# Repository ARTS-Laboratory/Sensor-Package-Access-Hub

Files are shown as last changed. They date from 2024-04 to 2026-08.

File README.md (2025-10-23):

# Sensor Package Access Hub
An access hub for communicating with the lab's sensor packages over short-range RF

## Licensing and Citation

[][cc-by-sa]

This work is licensed under a
[Creative Commons Attribution-ShareAlike 4.0 International License][cc-by-sa].

[cc-by-sa]: http://creativecommons.org/licenses/by-sa/4.0/
[cc-by-sa-image]: https://licensebuttons.net/l/by-sa/4.0/88x31.png
[cc-by-sa-shield]: https://img.shields.io/badge/License-CC%20BY--SA%204.0-lightgrey.svg

Cite as:

TBD

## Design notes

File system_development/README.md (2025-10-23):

# System Development

## V0.1
* 2022-2023 Senior Design

## V0.2
* 2023-2024 Senior Design
* Achieved short-distance wireless communication between two Teensy 4.0 microcontrollers and processed the data gathered by the dummy sensor package on the Raspberry Pi.

## V0.3
* Water Flooding Project

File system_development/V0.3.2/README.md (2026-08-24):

Documenting prior ELCT403 and current/future 404 work under this version no.

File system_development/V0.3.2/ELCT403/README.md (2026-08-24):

Contains Teensy 3.5 Arduino sketchs used in ELCT403 Senior Design I for early project development, with focus on interfacing nRF24 and LoRa radio modules.

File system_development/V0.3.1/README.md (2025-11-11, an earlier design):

# V0.3

PCB view-
<div class="side-by-side-container">
  <figure>
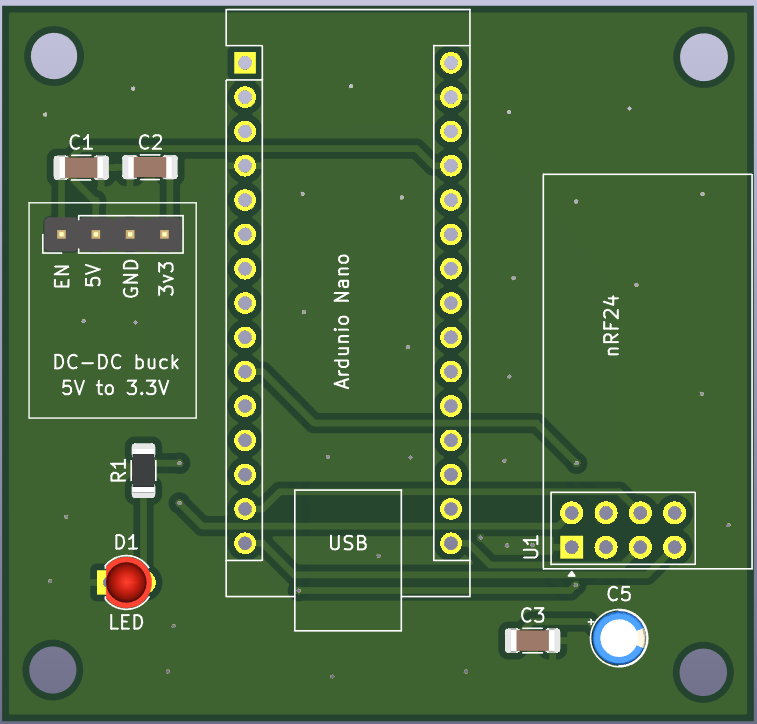
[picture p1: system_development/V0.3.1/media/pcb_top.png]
PCB top
    
  </figure>     
  <figure>
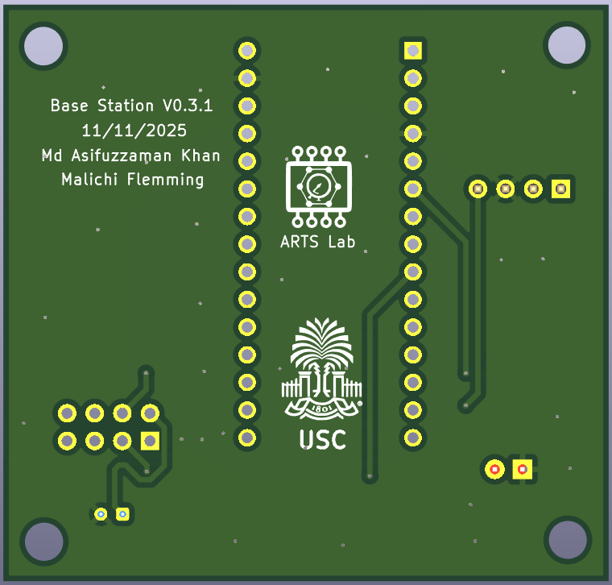
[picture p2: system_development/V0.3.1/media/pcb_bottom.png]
PCB bottom
    
  </figure>
</div>
* Reference from - https://github.com/ARTS-Laboratory/IoT-Water-Level-Sensor

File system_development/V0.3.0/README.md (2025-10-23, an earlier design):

# V0.3

* Start by copying from - https://github.com/ARTS-Laboratory/Smart-Penetrometer-with-Edge-Computing-and-Intelligent-Embedded-Systems/tree/main/SYS_DEV/Columbia/V0/V0.6/V0.6.2/base_station
* Reference from - https://github.com/ARTS-Laboratory/IoT-Water-Level-Sensor

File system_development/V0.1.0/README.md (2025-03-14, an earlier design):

# Sensor-Package-Access-Hub (2022-2023 Senior Design Project)
Team Cell-U-Later

## Team members
1. Crean, Kevin
1. Dye, Hudson
1. Hill, Wyatt
1. Hobbs, Davis

## Hardware
* Botletics SIM7000A (cellular chip)
* Hologram Global IoT microSim card
* IoT subscription
* Used a hologram.io for this under a team account.

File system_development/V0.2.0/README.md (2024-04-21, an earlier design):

#Team Smoaking Hot Software & Documentation

# Sensor Package & Waystation Contents

* Contains all software components and schematics used and tested in project

#Paperwork

* Contains all major assignments done for ELCT 403/404

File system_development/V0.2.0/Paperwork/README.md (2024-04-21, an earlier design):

#Paperwork

# ELCT404_Final_Presentation

* Final Presentation for Project

#TechnicalManualSmoakingHot

* Achieved performance specifications
* Schematics
* Diagrams
* Operating instructions
* Troubleshooting tips

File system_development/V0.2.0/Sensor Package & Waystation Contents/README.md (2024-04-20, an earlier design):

# Sensor-Package-Access-Hub (2023-2024 Senior Design Project)

## Accel_tockn
* Working sensor code. Only gathers accelerometer data and stores it in SD card

## Sensor_Package_Code:

* 1st attempt at transmitting accelerometer data (failed)

## Working One Way Data Transmission:

* Successful data transmission from Teensy to Teensy
* Contains Sensor Package code and serial outputting receiver
* PCB Design Folder contains PCB schematics for the working iteration of the code.
* Raspberry Pi Code contains working code for the waystation operating using Teensy to Teensy/Pi

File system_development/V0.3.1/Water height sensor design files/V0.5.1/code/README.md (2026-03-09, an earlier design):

## clock_calibration
- calibrates the DS3231 to compiling time or a user defined time

## OS_0.5.0
- Operating system for base package data collection

## Programming instruction
- Upload the clock calibration program first, then without unplugging the board, upload the OS code.

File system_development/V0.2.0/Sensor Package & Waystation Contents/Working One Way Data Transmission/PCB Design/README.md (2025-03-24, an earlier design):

# PCB Design

## V0.3.0
* All components on board

## V0.4.0
* Add holes for standoffs
* Compress board size
* Added silkscreen logo, designer names, part names, version number, 
* Add a ground plane
* Different footprint for Teensy

## V0.4.1
* Adjusted hole size
* Fixed lettering
* Added through holes for ground plane
* Extended Board

## V0.4.1

* Adjusted hole size for MPU6050
* Added surface mounts for linear regulators

## V0.5.0

* New version in March 2025 for future changes.

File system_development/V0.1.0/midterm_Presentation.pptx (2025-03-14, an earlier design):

## TEAm cell-u-later

End of Term Presentation
Kevin Crean, Hudson Dye, Wyatt Hill, Davis Hobbs

## Agenda

- Team Overview
- Subsystem Progress
  - Wireless Communication
  - User Interface
  - Onboard Processing
  - Power Distribution and Management

## Project Overview

Project Mission: Create a data collection waystation that collects data from deployed sensor packages, computes structural health metrics, and sends the metrics through a commercial cellular network.
Project Description:
- Wireless communication between the waystation and the sensors.
- Onboard computing at waystation to calculate structural health metrics.
- Results passed on to a host PC via commercial cellular network

## System Block Diagram

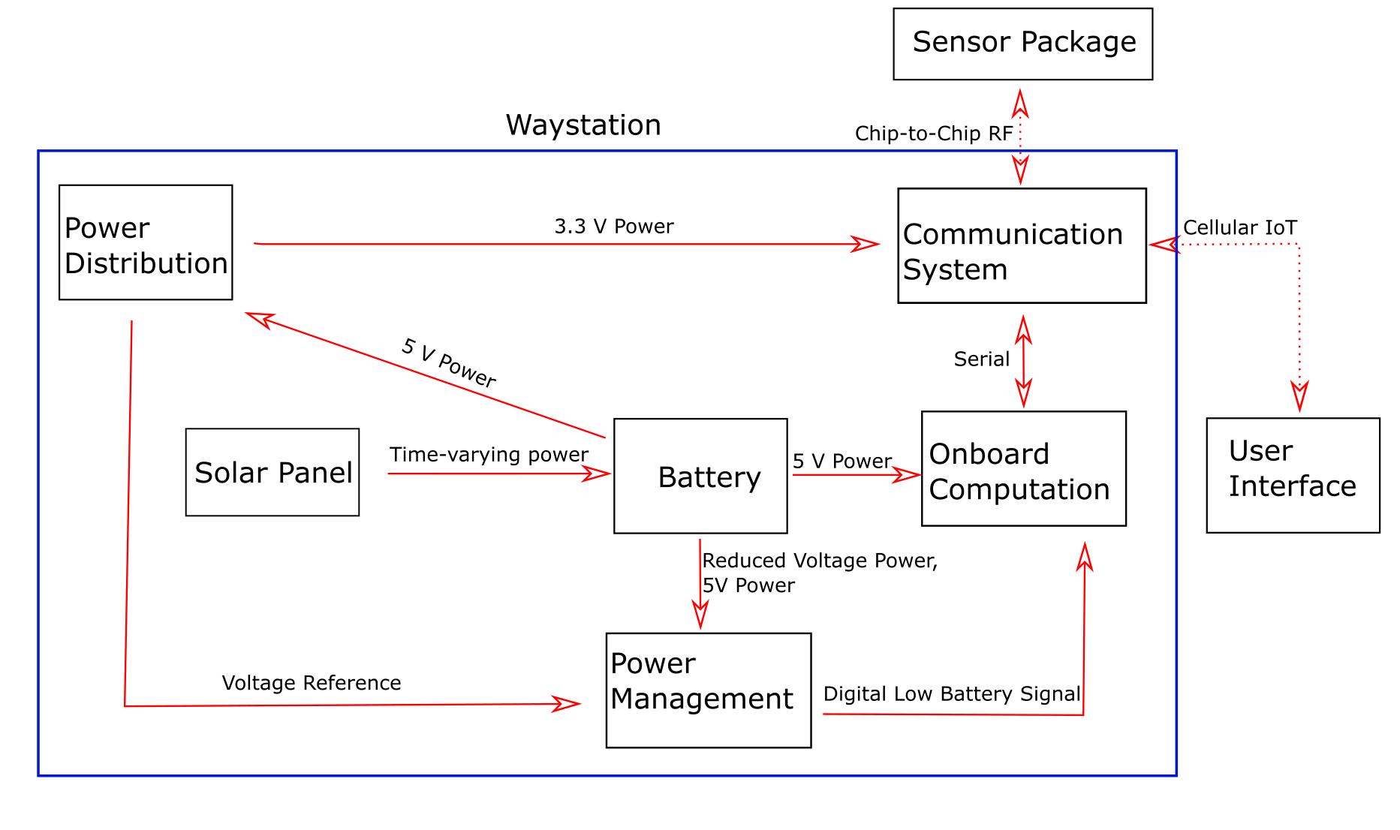
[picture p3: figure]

## Design Philosophy

- Physical Limitations: Size and Weight
- Monetary Limitations: Pricing
- Ease of Implementation
- ADD DIAGRAM

## Team organization

- Project Sponsor: Austin Downey
- Team Lead: Kevin Crean
- Onboard Processing Subsystem: Kevin Crean
- Wireless Communication: Hudson Dye
- Power Distribution and Management: Davis Hobbs
- User Interface: Wyatt Hill

## Project status: Schedule

- Acquired all necessary parts to prototype entire system
- Completed subsystem demonstrations
- Meeting consistently at least once a week

## Project status: Financials

Component | Price
Botletics SIM700A-LTE-Shield (2) | $65
Micro SIM card + IoT subscription | $5
LP311P Differential Comparator (2) | $3
OKR-T-3-W12-C Buck Converter (2) | $16
SUNER BC-10 Solar Panel | $56
Talent Cell 5V/12000mAh Lithium-ion Battery | $40
SAE– Barrel Jack adapter | $10
| $195

## High Level Problems

- Transferring pre-packaged data to generic data files
- Power Management for regulated battery voltage
- Understanding new concepts
  - RF Communication/Protocol

## Wireless Communication subsystems

- Hudson Dye

## Block Diagram – communication focused

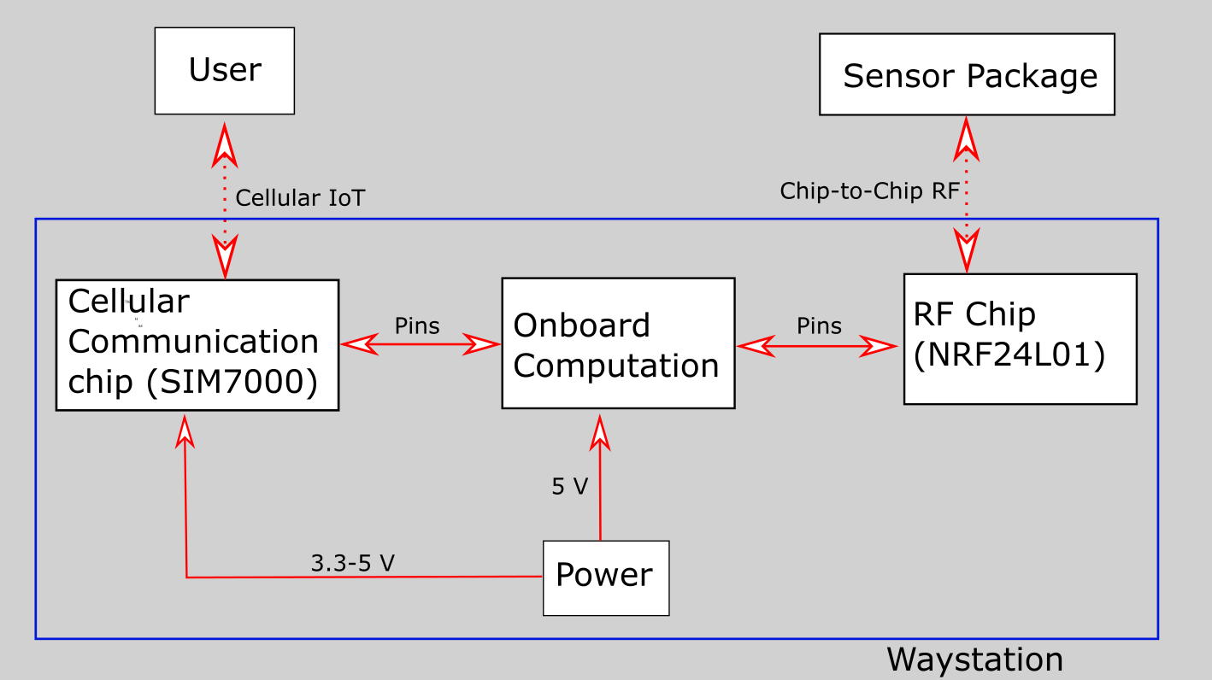
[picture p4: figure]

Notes: Please change background color of this picture to white

## Block Diagram – Information flow

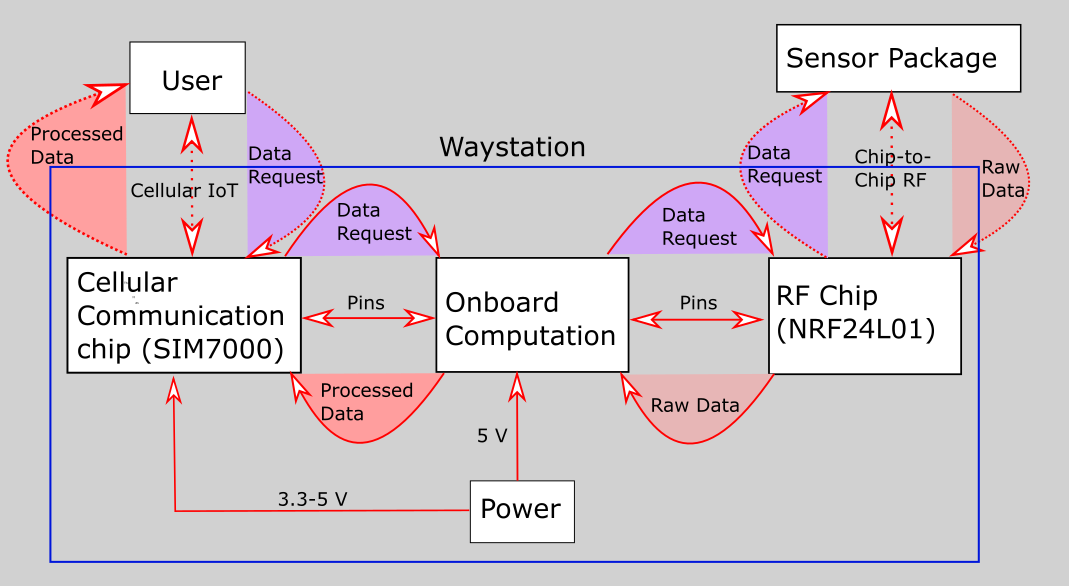
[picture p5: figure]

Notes: Please change background color of this picture to white

## Wireless subsystems

- Cellular Communication

- Cellular chip + microSIM
- IoT connection to user

- Chip-to-Chip RF

- NRF chip
- Previously implemented RF connection

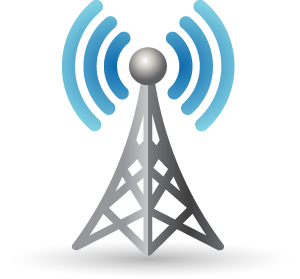
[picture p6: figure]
Cell Tower Icon Png #145130 - Free Icons Library
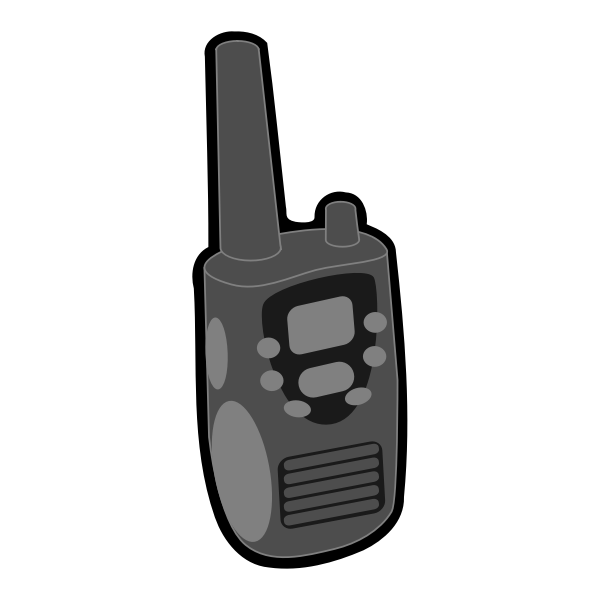
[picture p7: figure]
Walkie talkie | Free SVG

## Cellular Communication functions

- Read chip & source information
  - battery voltage, ID, etc.
- Read wireless environment information
  - registration status, RSSI, network time, etc.
- Send/Receive SMS
- post chip information to dweet.io

Goal: Send files to user via IoT

## Cellular Characterization

- This slide may include evidence of functioning cellular IoT capabilities

## Learning Process

- Custom PCB necessary to use any microcontroller except Arduino
  - Use Arduino Uno for prototyping
- Spent ~25 hours testing faulty chip
  - Provided with free replacement extensive troubleshooting with CEO
  - Will need to play catch up during Christmas for RF portion
- This delayed RF communication implementation

## user interface (UI) Subsystem

- Wyatt Hill

## UI Subsystem overview

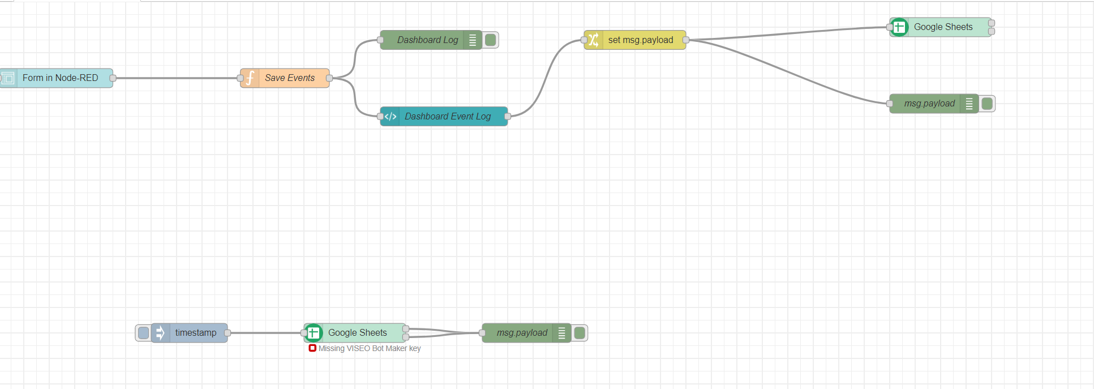
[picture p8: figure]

## UI Subsystem Functions

- Read Function
  - Ability to read and display data from data storage
  - Ability to select specific points and periods of data and read and display it from data storage.
- Write Function
  - Ability to write to data storage for use of the read function
  - Ability to write processed data real time when requisition is given

## Ui Read function Experiment

- The Data sheet is loaded with mock data
  - First Name
  - Last Name
  - Country
- The read function is called from UI as in normal operation
- The debug window of the UI will be populated with mock data if the read function is successful

## UI Experimental results

- 2 trials with different names and countries were successful

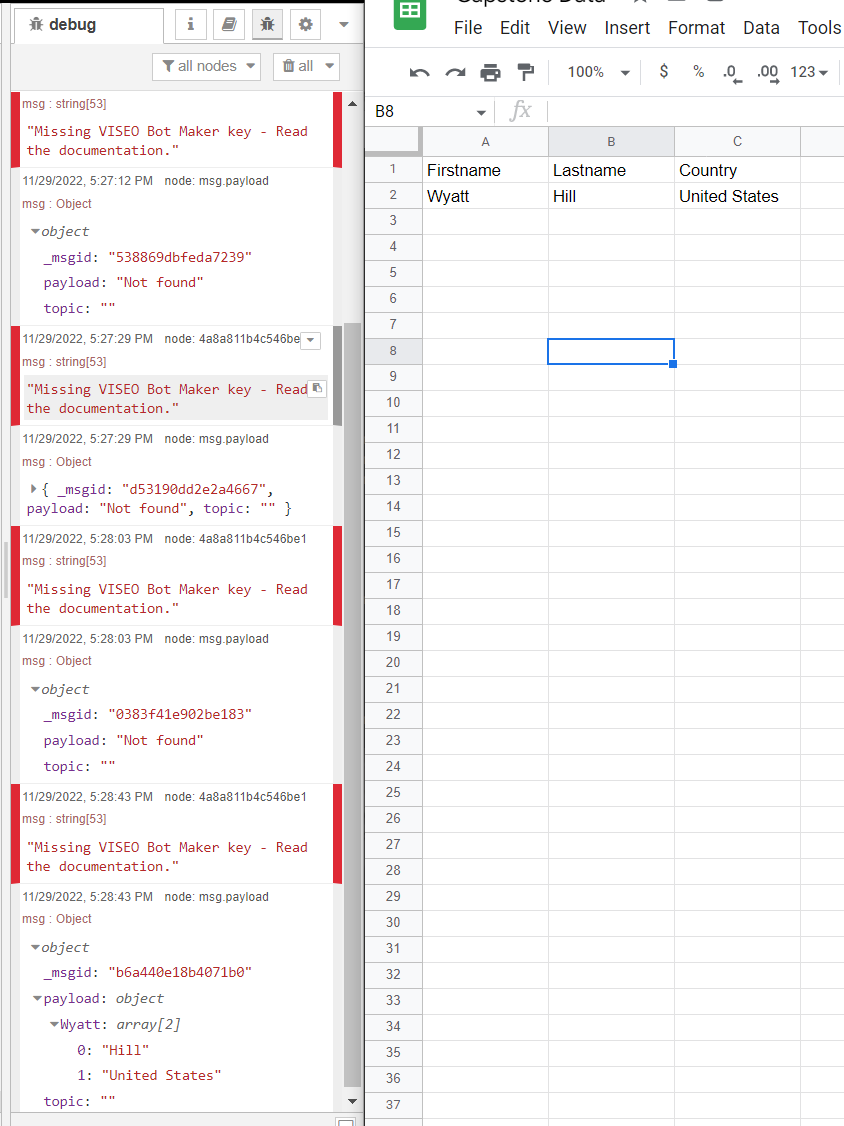
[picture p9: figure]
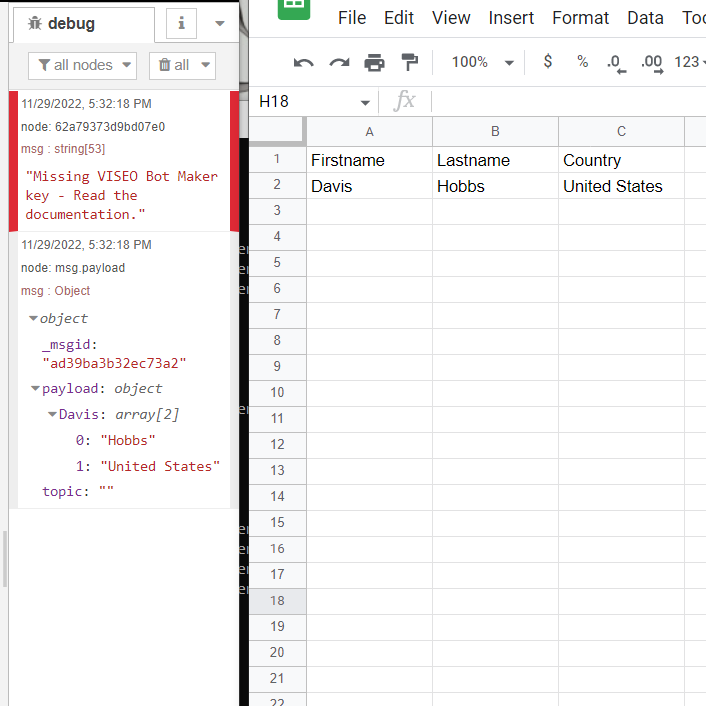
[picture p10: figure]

## UI Subsystem Next steps

- Work with Communication subsystem to achieve completion of write function.
- Implement user input window for read function of UI subsystem
- Integrate functions to successfully interface with local storage

## Onboard processing subsystem

- Kevin Crean

## Onboard processing subsystem objective

- Microcontroller receives and saves raw data to SD card.
- Code will perform the structural health metrics that are requested.
- Once metrics are calculated, processed data will be sent wirelessly to the user interface.

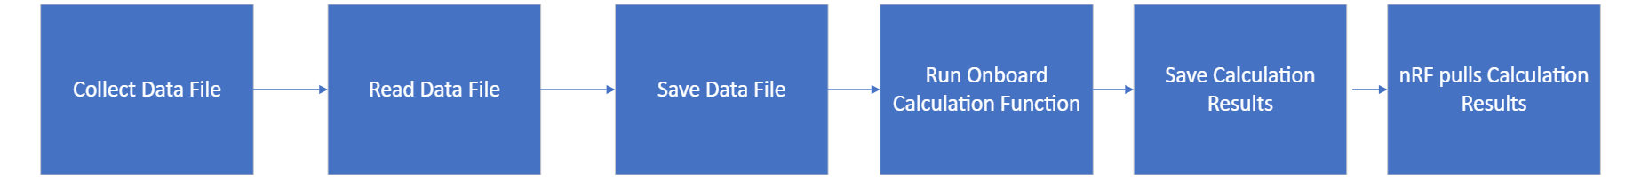
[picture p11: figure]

## Onboard processing Experiment: Read and Write SD Card

- Read and Write to test file contained on SD Card
- Print out Results on Serial Monitor
- Serial Peripheral Interface (SPI) Protocol.

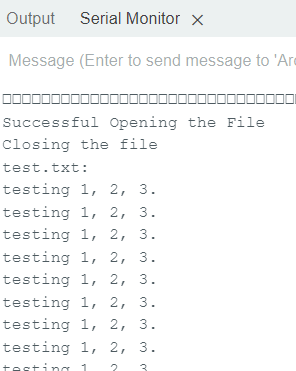
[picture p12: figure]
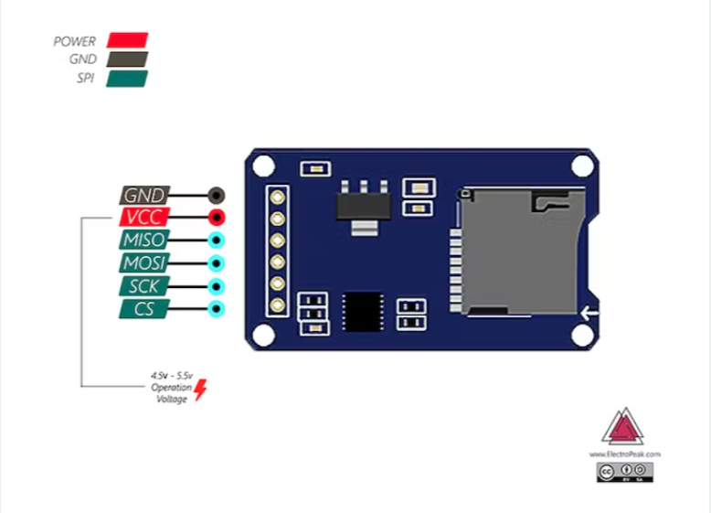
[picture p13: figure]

## Onboard processing Experiment: Mean function

- Stores Data in an Array
- Finds the Average Value
- Running Average Function

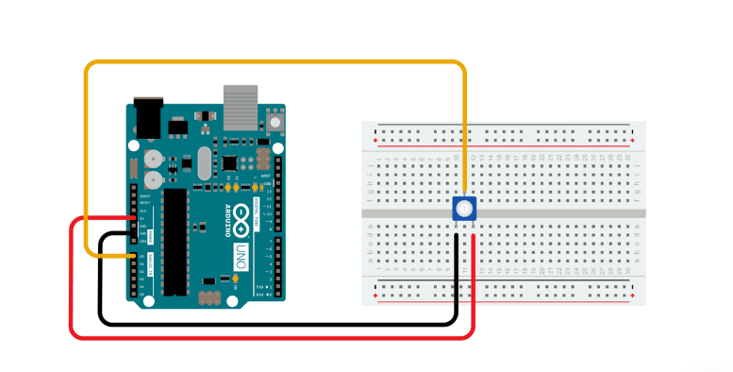
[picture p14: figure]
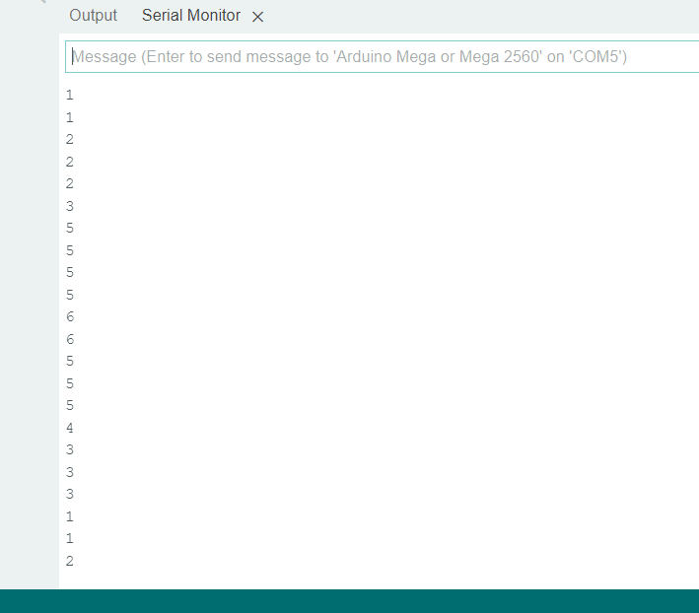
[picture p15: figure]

## Onboard processing problems and concerns

- Learning Arduino Programming Language
  - Some parts taking longer than expected
- Fast Fourier Transform Function
  - Low Resolution that Arduino Mega 2560 R3 will be able to compute
- Switching to a Raspberry Pi
  - Potentially Delay Gantt Chart Schedule

## Onboard processing next steps

- Combine and Adjust Mean Function Calculation Code with Read/Write SD Card Code
- Write Fast-Fourier Transform Function
- Microcontroller communication with nRF module
- Using a Raspberry Pi instead of the Arduino Mega 2560 R3

## Power Distribution and Management (PDM) Subsystem

- Davis Hobbs

## PDM Subsystem Overview

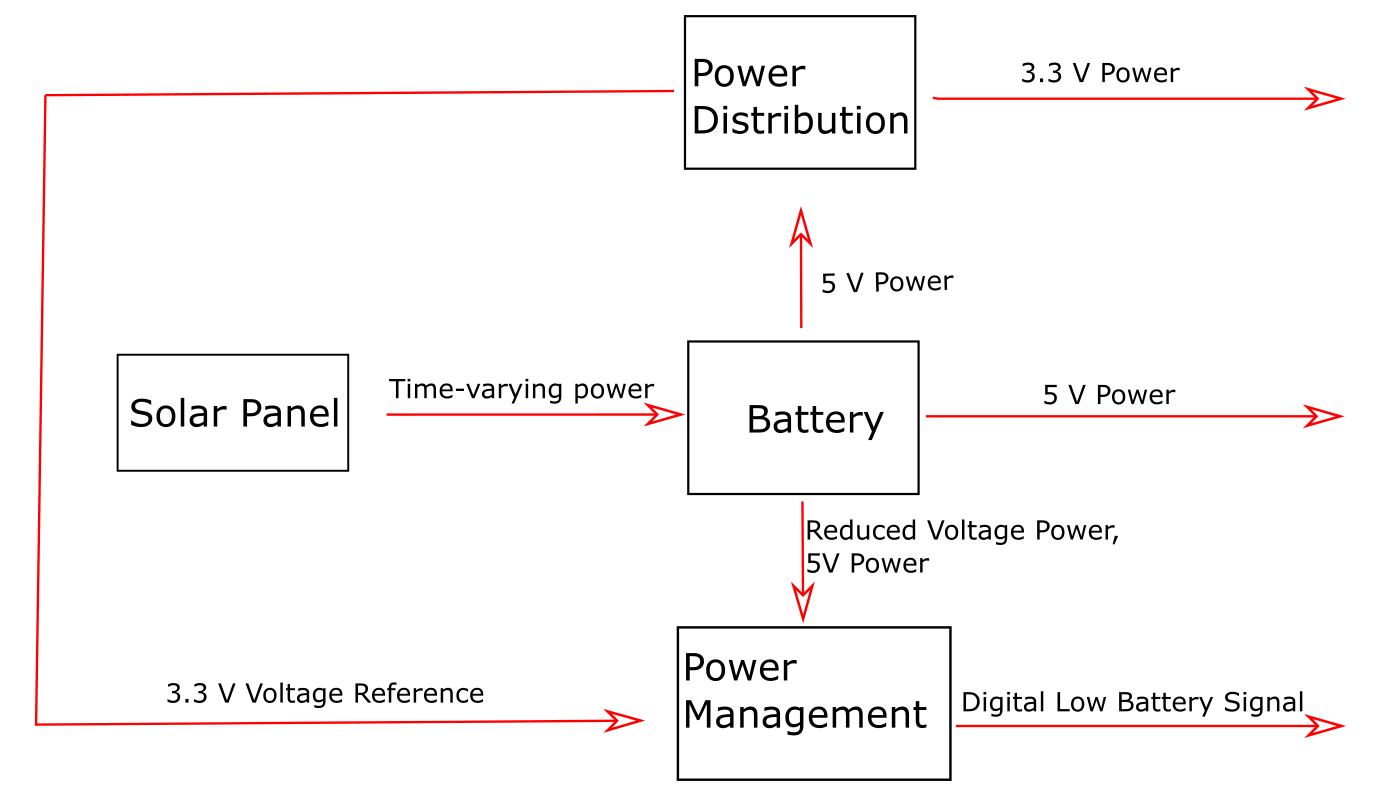
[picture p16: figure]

## PDM Subsystem Objectives

- Power Supply
  - Establish a ~5 V power source to supply the microcontroller
  - High capacity with solar recharge capabilities
- Power Distribution
  - Establish a ~3.3V power source to supply the comms hardware
  - Capable of enduring rapid changes in load
- Power Management
  - Signal the microcontroller when the battery is at low capacity

## Subsystem Hardware: Power Supply

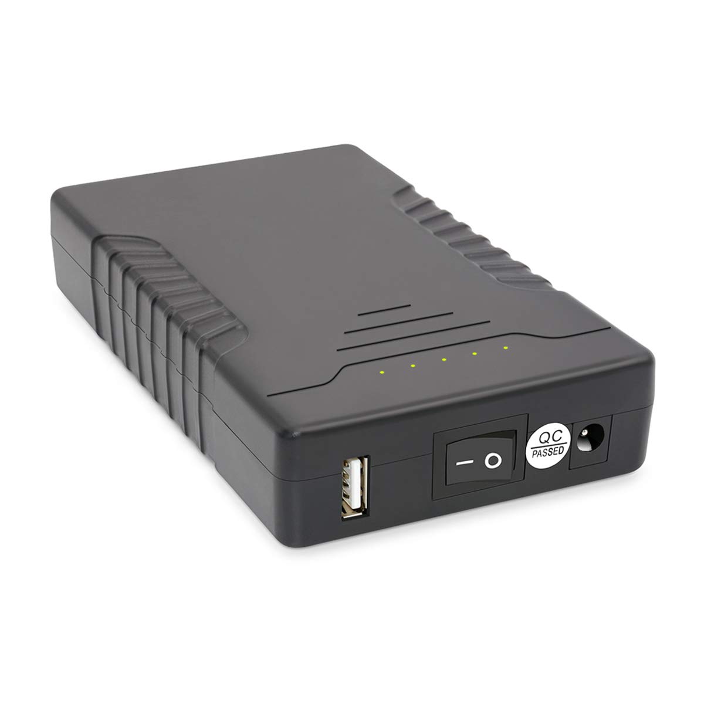
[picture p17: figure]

- A 5V Talent Cell Battery was selected
  - Internal 5V regulator to reduce voltage ripple
  - Internal battery management system allows for solar panel integration
  - Sufficient capacity for 4 days of operation using data sheet values
- The battery is supported by a 12 W Suner Solar Panel
  - Interfaces with battery via an SAE connector
  - Designed for Li Battery charging

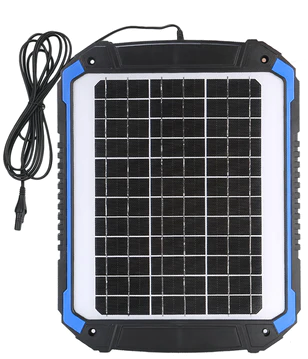
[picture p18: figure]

## Subsystem Hardware: Power distribution

- OKR buck converter supplies power to comms hardware.
  - Reduces ~5V battery voltage to ~3.3V
  - Up to 93% efficient power conversion
  - Highly effective at responding to pulsed loads
- Converter has been experimentally validated to supply loads mimicking the comms hardware

## Distribution System Experiment

Buck Converter

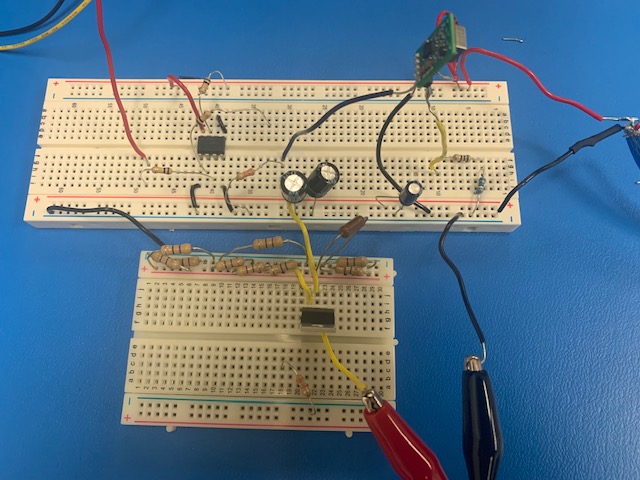
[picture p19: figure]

Base Load

Battery: 5 V

- The distribution system was given a load meant to mimic comms hardware power draw.
- This load was turned on and off at 15 Hz.
- The effect of dynamic loading on distribution output voltage was monitored.

Mosfet

High current load

Mosfet Gate Signal

## Experimental Results

- The buck converter can successfully reduce battery supply voltage
- The distribution subsystem provided a max load voltage range of 3.35 – 3.14 V
  - This range falls well within the 3.0 – 3.6 V range acceptable by the comms hardware.

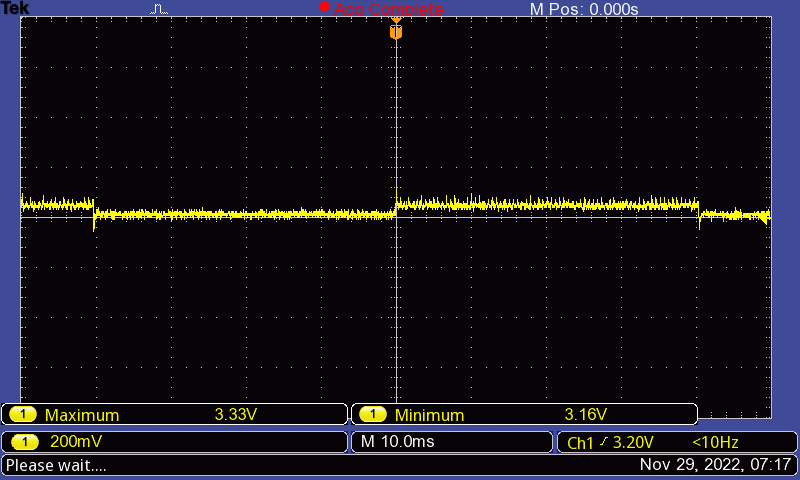
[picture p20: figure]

## Subsystem Hardware: Power Management

- The LP311P comparator was selected
  - Tracks battery voltage fade
  - Alerts microcontroller of low battery voltage
  - Microcontroller provides signal voltage to avoid overvoltage
- This subsystem was experimentally validated

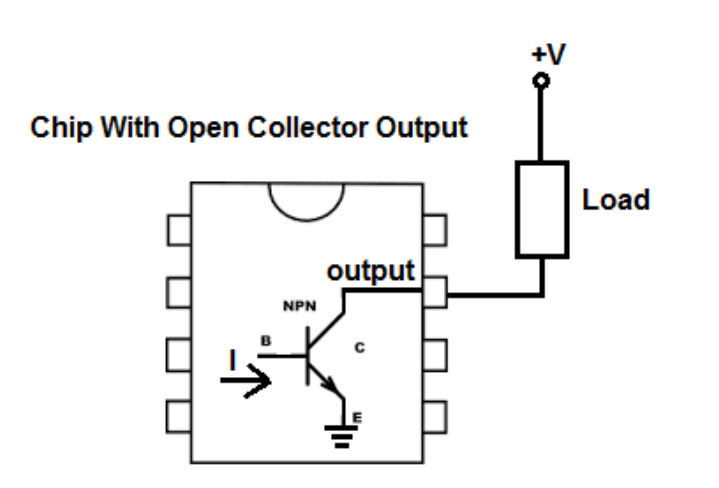
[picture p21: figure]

## Power Management Experiment

Buck Converter

Test Signal

Load Resistor

Supply: 5 V

- The power management hardware was supplied with a 3.3 V reference signal
- A power supply was used to mimic battery voltage fade
- The output signal of the comparator was monitored

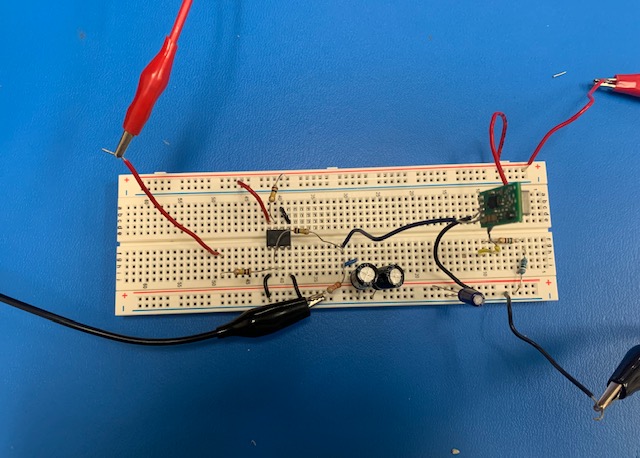
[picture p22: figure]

Comparator

## Power Management Experimental Results

- Demonstrated to Professor Smoak
- A digital signal does change from 0 V to 5.15 V when the input falls below the reference
- This validates the signal is accurate under static load conditions

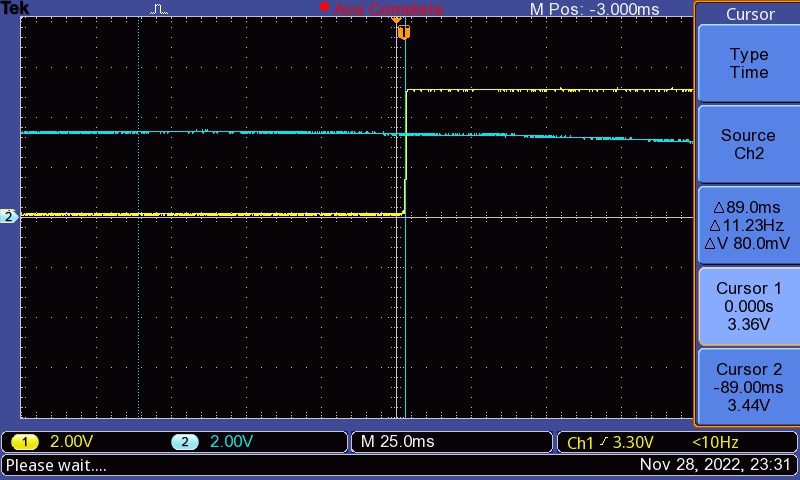
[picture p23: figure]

## PDM Subsystem: next steps

- The original design of the power management system did not anticipate regulated battery voltage
  - Necessitates a redesign of the power management system
- The solar panel’s ability to charge the battery will be tested
- Distribution hardware should be integrated with the comms hardware to test functionality

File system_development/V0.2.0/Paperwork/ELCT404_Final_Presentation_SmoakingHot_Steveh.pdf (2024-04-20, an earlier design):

# ELCT 404 Final Presentation

## Team:Smoaking Hot

4/14/2024

## Meet The Team: Smoaking Hot

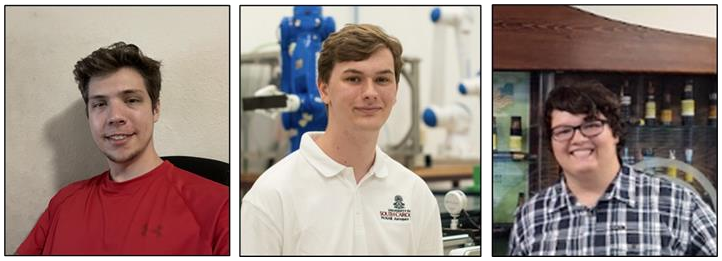
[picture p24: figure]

Jacob Tapp | Steve Howard | Jared Peters

## Project Overview

The objective of this project is to create a waystation that collects data from the sensors packages on a bridge via wireless communication. This data should then be processed and converted into a csv file with various forms of information such as standard Deviation, mean, and Fast Fourier Transformations (FFT’s) to provide insight of the bridges structural integrity.

## Design Philosophy

Our team's vision is to provide smoking hot products that are innovative and reliable. This is achieved by our philosophy that centers around ease and scalability.

- Affordable and reusable materials
- Flexible
- Repeatability
- Stability
- Hazardous conditions
- Risk Mitigation

## System Requirements


- Wireless communication
- Onboard Processing
- Power Management
- Storage Capacity
- Low Cost

## Achievements

- Wireless communication has been accomplished
- Teensy to Teensy/PI
- PCB Design
- Different Variations
- Tested First PCB
- Designed Second PCB
- Onboard Processing has been finished and successfully shows data
- Team has accomplished the scope of the project

## Financials

A large goal for this project is repeatability and low cost. Due to this we have resorted to recycling materials and finding cost effective materials.


## Problems Faced

- Understanding nRF chips
- Research
- Transmitter Issues
- Minimum power line code
- Range restrictions
- Raspberry Pi Issues
- Inexperience
- Wireless communication
- PCB issues
- Inexperience

## Individual Contributions:

- Project Planning
- Determine Project scope and deliverables
- Team Coordination
- Build and lead a high-performing team by assigning achievable tasks and responsibilities
- Resource Management
- Ensure that the team has the necessary equipment to perform their tasks
- Communication
- Planned Meeting Times with Sponsor and Team
- Ensured everyone communicated regarding the interconnects of subsystems

## Sensor Package Functionality

- Gather accelerometer data
- Measures intensity of a vibration at the point it is attached to on the structure
- Store data on SD card
- Allows for manual data retrieval if needed
- Transmit Data to waystation
- Send accelerometer data to waystation for computation

## Teensy 4.0


- Programmable microcontroller used for prototyping
- SPI bus
- 2 subsystems
- Digital pins

## SD Card Module

- Interfaces with micro SD card
- Uses SPI bus
- Has its own unique chip select pin
- SD card data stored in a .csv file


## MPU6050 Accelerometer


- Multipurpose sensor
- Accelerometer
- Gyroscope
- Internal thermometer
- Accelerometer measures in magnitudes of gravity

## NRF24L01

- Device that uses radio frequency to achieve wireless communication
- SPI bus
- Has its own chip select pin
- Range limitations
- Small antennae
- Teensy to Teensy currently working at ~2ft apart


## Sensor Package Code Flow Chart


## Sensor Package Future Iterations

- Turn it into a transceiver
- Will be prompted by the waystation to record and transmit data
- Achievable by transmitting a basic true/false message to the sensor package

# Onboard Processing

## By: Steve Howard

## Raspberry Pi Setup


- Raspberry Pi Setup
- Downloaded Raspberry OS
- Troubleshooted setup for Pi due to network issues at UofSC
- Wired nRF chip to Raspberry Pi
- Setup Libraries

## Onboard Processing

Once the Data is on the PI then it needs to be processed into information for the user to access bridge infrastructure.

- Accessible Data:
- Mean
- Standard Deviation
- Fast Fourier Transformations

## Onboard Processing Code

## Demonstration


## What's Next

- Turn the PI into a transceiver
- Remove extra teensy
- Order the new set of PCB's
- Begin testing with the new nRF modules
- Design Physical Waystation
- Weatherproof
- Easily accessible
- Secure

## Special Thanks:

We would like to express our sincere gratitude to the following individuals for their invaluable contributions and unwavering support:

- Austin Downey
- Ryan Yount
- Wilson Smoak
- Joe Gucwa

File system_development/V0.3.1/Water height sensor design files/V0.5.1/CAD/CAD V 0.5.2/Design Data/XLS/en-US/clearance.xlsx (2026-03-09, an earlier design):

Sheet: Ansi Unified Screw Threads
I | Sort Order -1
Fastener Type | Size | Shaft Diameters |  |  | Head Dimensions
 |  | Close | Normal | Loose | Diameter | Depth/Angle | Head Type
Flat Head Machine Screw (82) | #0 | 0.0635 | 0.07 | 0.073 | 0.119 | 82 | 2
Flat Head Machine Screw (82) | #1 | 0.076 | 0.081 | 0.089 | 0.146 | 82 | 2
Flat Head Machine Screw (82) | #2 | 0.089 | 0.096 | 0.1065 | 0.172 | 82 | 2
Flat Head Machine Screw (82) | #3 | 0.104 | 0.11 | 0.12 | 0.199 | 82 | 2
Flat Head Machine Screw (82) | #4 | 0.116 | 0.1285 | 0.136 | 0.225 | 82 | 2
Flat Head Machine Screw (82) | #5 | 0.1285 | 0.136 | 0.154 | 0.252 | 82 | 2
Flat Head Machine Screw (82) | #6 | 0.144 | 0.1495 | 0.1695 | 0.279 | 82 | 2
Flat Head Machine Screw (82) | #8 | 0.1695 | 0.177 | 0.1935 | 0.332 | 82 | 2
Flat Head Machine Screw (82) | #10 | 0.196 | 0.201 | 0.221 | 0.385 | 82 | 2
Flat Head Machine Screw (82) | #12 | 0.221 | 0.228 | 0.246 | 0.438 | 82 | 2
Flat Head Machine Screw (82) | 1/4 | 0.257 | 0.266 | 0.2812 | 0.507 | 82 | 2
Flat Head Machine Screw (82) | 5/16 | 0.323 | 0.332 | 0.3437 | 0.635 | 82 | 2
Flat Head Machine Screw (82) | 3/8 | 0.386 | 0.397 | 0.4062 | 0.762 | 82 | 2
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

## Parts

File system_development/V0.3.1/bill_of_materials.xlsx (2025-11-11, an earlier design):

PCB Designator | Component | Amount | Unit | Individual Cost | Total Cost | Vendor 1 | Vendor 2 | Vendor 3
Arduino Nano | Arduino Nano | 1 | pc | $10.89 | $10.89 | https://www.digikey.com/en/products/detail/universal-solder-electronics-ltd/26014/26606379?gclsrc=aw.ds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
N/A | 5.1V 5A PD USB-C adapter for PI | 1 | pc | $12.00 | $12.00 | https://www.digikey.com/en/products/detail/raspberry-pi/SC1153/21658276?gclsrc=aw.ds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 | https://geekworm.com/products/pd27w?srsltid=AfmBOoqyL0Kvsjw1AYgA_HRXV8IIYj1cuPRJD8sKZCJ0dOIFZ0BI-Szp
N/A | Raspberry PI 5, 2GB RAM | 1 | pc | $50.00 | $50.00 | https://www.digikey.com/en/products/detail/raspberry-pi/SC1642/24627138 | https://www.adafruit.com/product/6007 | https://www.mouser.com/ProductDetail/Raspberry-Pi/SC01949?qs=T%252BzbugeAwjjISb%252BwlagpRw%3D%3D
DC-DC buck | 5V to 3.3V buck converter | 1 | pc | $4.95 | $4.95 | https://www.digikey.com/en/products/detail/sparkfun-electronics/COM-18357/15189221?gclsrc=aw.ds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 | https://www.sparkfun.com/sparkfun-babybuck-regulator-breakout-3-3v-ap63203.html
nRF24 | NRF24L01+PA+LNA 2.4GHz Wireless RF Transceiver Module | 1 | pc | $3.95 | $3.95 | https://protosupplies.com/product/nrf24l01palna-2-4ghz-rf-wireless-module/ | https://www.elecbee.com/en/product-detail/1100-meter-long-distance-nrf24l01-pa-lna-wireless-module-with-antenna-module_73275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 | https://openelab.io/products/nrf24l01-transceiver-transceiver-module
N/A | PCB | 1 | pc | $8.23 | $8.23 | https://oshpark.com/
N/A | 64 / 32 GB MicroSD card | 1 | pc | $6.60 | $6.60 | https://www.digikey.com/en/products/detail/raspberry-pi/SC0339L/12339165?gad_source=1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 | https://www.staples.com/verbatim-premium-64gb-microsdxc-memory-card-with-adapter-class-10-uhs-i-v10-44084/product_2478898 | https://www.cdw.com/product/sandisk-extreme-flash-memory-card-64-gb-microsdxc-uhs-i/7316165?pfm=srh
D1 | 3mm Red 620nm LED Indication - Discrete 1.85V Radial | 1 | pc | $0.20 | $0.20 | L314ED American Opto Plus LED | Optoelectronics | DigiKey Marketplace (https://www.digikey.com/en/products/detail/american-opto-plus-led/L314ED/13677700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) | https://www.lvelectronics.com/details/item?itemid=AOP%20L314ED
R1 | 270 Ohms ±5% 0.25W, 1/4W Chip Resistor 1206 (3216 Metric) | 1 | pc | $0.10 | $0.10 | https://www.digikey.com/en/products/detail/stackpole-electronics-inc/RMCF1206JT270R/1757430 | https://www.digikey.com/en/products/detail/stackpole-electronics-inc/RMCF1206FT270R/1759786
C5 | 10 µF 25 V Aluminum Electrolytic Capacitor Radial | 1 | pc | $0.26 | $0.26 | https://www.digikey.com/en/products/detail/panasonic-electronic-components/ECE-A1EKS100B/2689095 | https://www.mouser.com/ProductDetail/Panasonic/ECE-A1EKS100B?qs=rMMd5vBiahpNSBku%2FPA9KQ%3D%3D
C1, 2, 3 | 0.1 µF ±10% 50V Ceramic Capacitor X7R 1206 (3216 Metric) | 2 | pc | $0.48 | $0.96 | C1206S104K5RACAUTO KEMET | Capacitors | DigiKey (https://www.digikey.com/en/products/detail/kemet/c1206s104k5racauto/10232834) | https://www.mouser.com/ProductDetail/KEMET/C1206S104K5RACAUTO?qs=ds50AKTGxA9C%252BOGFjvBCPg%3D%3D
 |  |  |  | Total Cost | $98.14

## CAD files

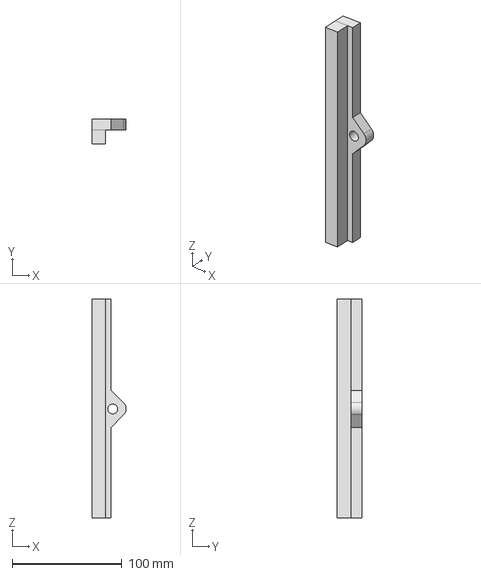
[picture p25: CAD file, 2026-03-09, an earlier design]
system_development/V0.3.1/Water height sensor design files/V0.5.1/CAD/Accessory/large solar panel bracket angled.stp
31.4 x 23.2 x 200.0 mm

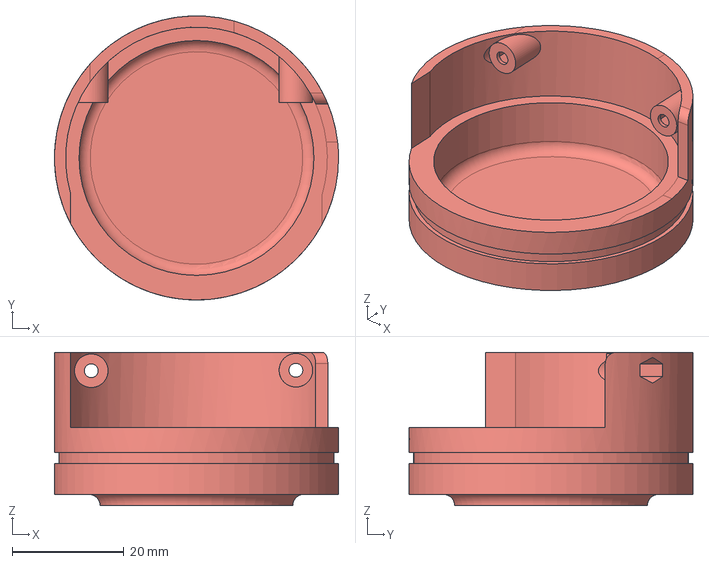
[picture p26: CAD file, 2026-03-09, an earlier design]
system_development/V0.3.1/Water height sensor design files/V0.5.1/CAD/CAD V 0.5.2/O-ring groove test/IR 24-6.step
50.8 x 50.8 x 27.4 mm

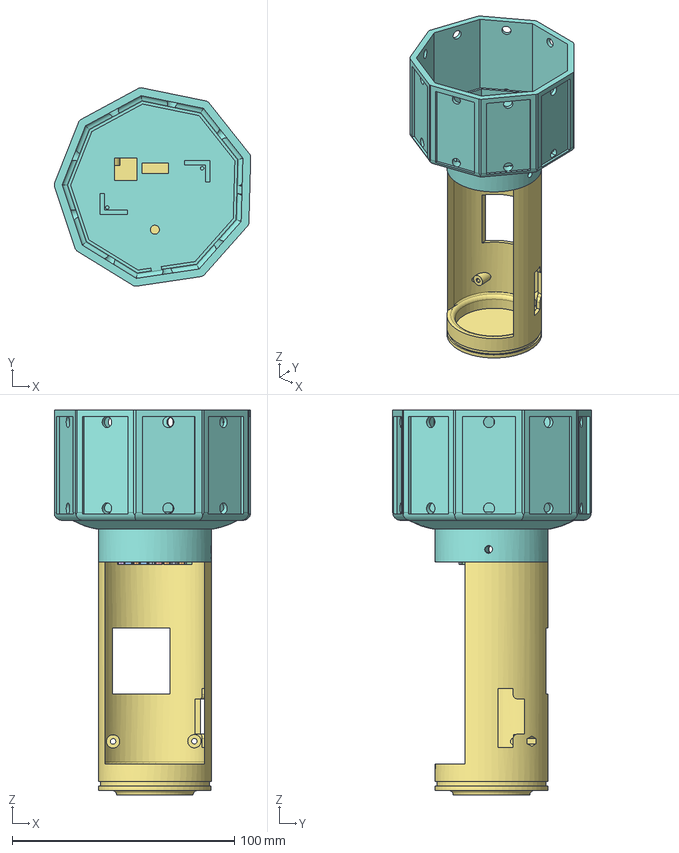
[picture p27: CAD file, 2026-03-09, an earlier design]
system_development/V0.3.1/Water height sensor design files/V0.5.1/CAD/CAD V 0.5.2/PCB tray CAD v2.step
88.4 x 89.3 x 173.2 mm

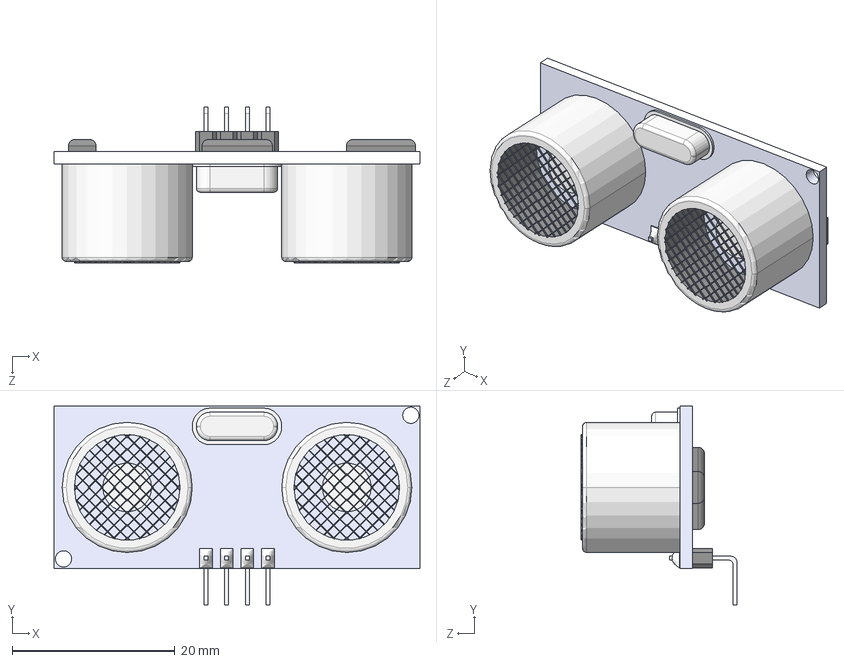
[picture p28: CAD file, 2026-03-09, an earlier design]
system_development/V0.3.1/Water height sensor design files/V0.5.1/CAD/Ultrasonic HCSR04.STEP
45.0 x 24.5 x 19.2 mm

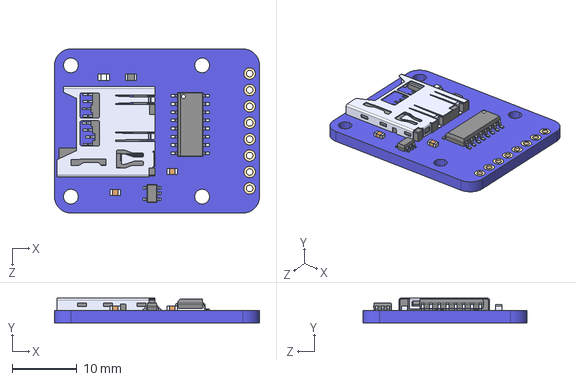
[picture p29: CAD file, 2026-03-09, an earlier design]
system_development/V0.3.1/Water height sensor design files/V0.5.1/EDA/lib_and_pretty/254/254.step
31.8 x 3.81 x 25.4 mm

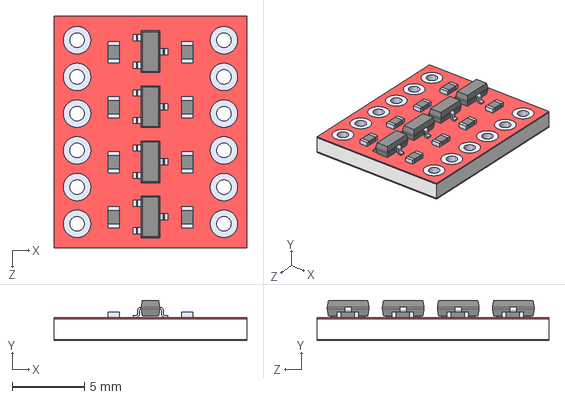
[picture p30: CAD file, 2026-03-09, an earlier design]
system_development/V0.3.1/Water height sensor design files/V0.5.1/EDA/lib_and_pretty/Logic level shifter/Logic_level_shifter.step
13.3 x 2.80 x 16.1 mm

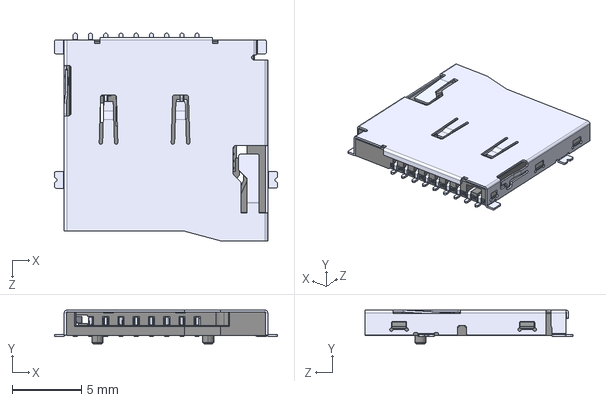
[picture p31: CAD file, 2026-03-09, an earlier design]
system_development/V0.3.1/Water height sensor design files/V0.5.1/EDA/lib_and_pretty/ST-TF-003A/ST-TF-003A.step
16.1 x 2.45 x 15.0 mm

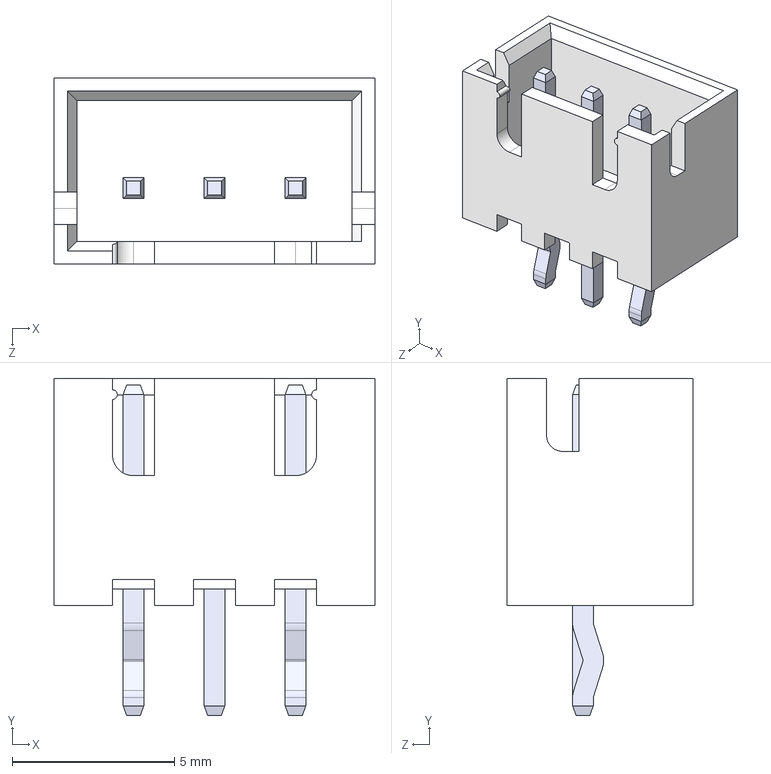
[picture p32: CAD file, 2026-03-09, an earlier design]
system_development/V0.3.1/Water height sensor design files/V0.5.1/EDA/lib_and_pretty/XH2.54/XH2.54..step
9.90 x 10.4 x 5.75 mm

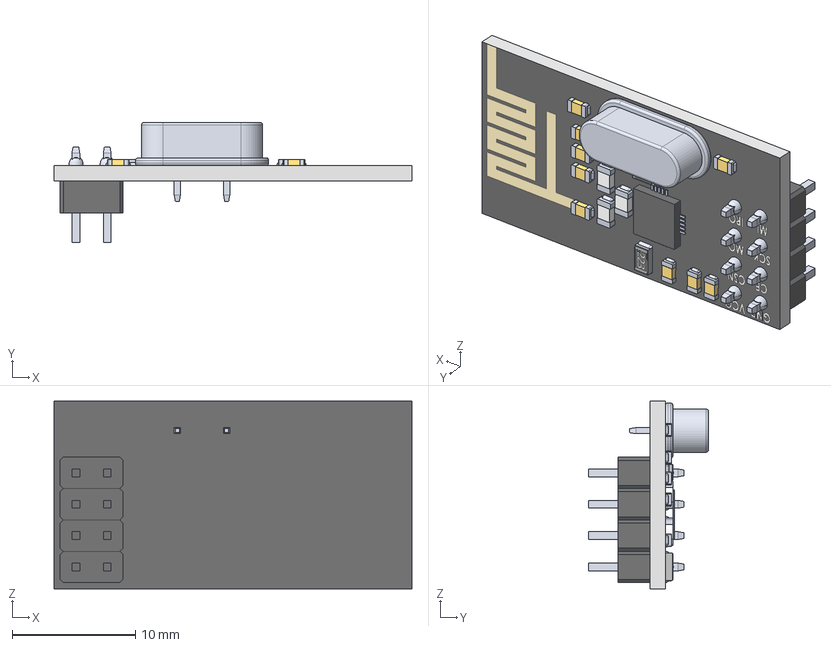
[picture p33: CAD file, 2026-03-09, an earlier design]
system_development/V0.3.1/Water height sensor design files/V0.5.1/EDA/main_board/module CAD/nRF24L01+1.STEP
29.0 x 9.75 x 15.2 mm
nrfboard
CrystalOscillator
doubleMaleHeader x 4
solder x 8
1.7mmSmdCeramicCapacitor x 9
smdResistor223
smdResistor105
smdceramiccapacitorwhite x 3
4x4SMDchip

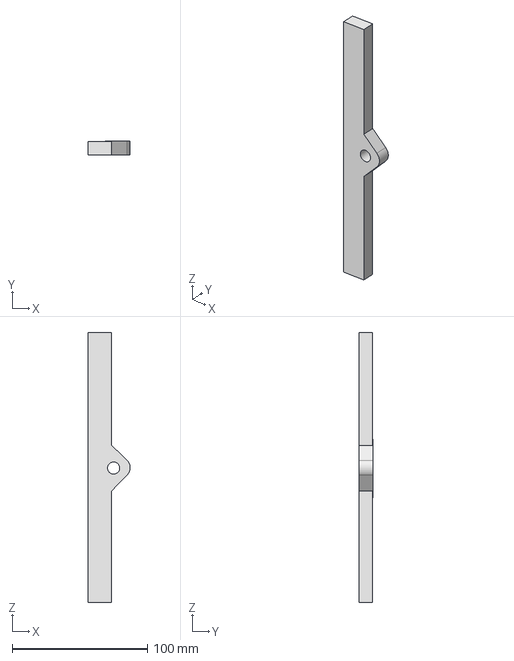
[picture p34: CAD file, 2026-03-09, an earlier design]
system_development/V0.3.1/Water height sensor design files/V0.5.1/CAD/Accessory/large solar panel bracket.stp
31.4 x 10.0 x 200.0 mm

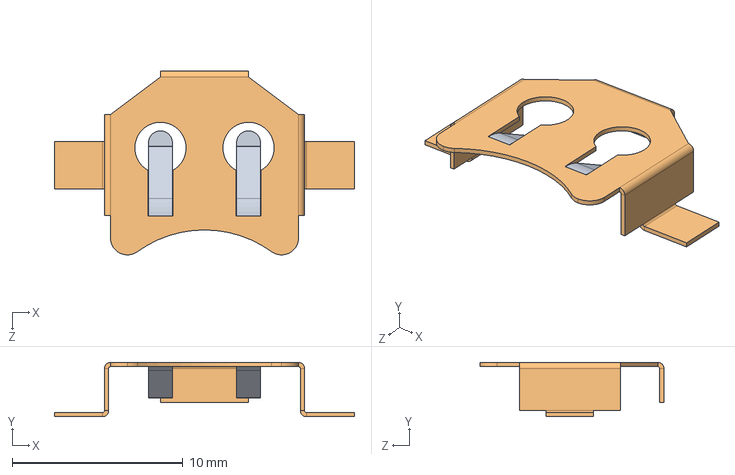
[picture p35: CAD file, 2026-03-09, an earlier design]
system_development/V0.3.1/Water height sensor design files/V0.5.1/EDA/main_board/module CAD/CR-1025-holder.STEP
17.6 x 3.18 x 10.8 mm

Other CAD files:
system_development/V0.3.1/Water height sensor design files/V0.5.1/CAD/CAD V 0.5.2/Templates/English/ANSI (in).dwg
system_development/V0.3.1/Water height sensor design files/V0.5.1/CAD/CAD V 0.5.2/Templates/Metric/GB.dwg
system_development/V0.3.1/Water height sensor design files/V0.5.1/CAD/CAD V 0.5.2/Templates/Standard.dwg
system_development/V0.3.1/Water height sensor design files/V0.5.1/CAD/CAD V 0.5.2/O-ring groove test/IR 23-7.step
system_development/V0.3.1/Water height sensor design files/V0.5.1/CAD/CAD V 0.5.2/Templates/Metric/BSI.dwg
system_development/V0.3.1/Water height sensor design files/V0.5.1/CAD/CAD V 0.5.2/O-ring groove test/IR 23-6.step
system_development/V0.3.1/Water height sensor design files/V0.5.1/CAD/CAD V 0.5.2/Templates/Metric/JIS.dwg
system_development/V0.3.1/Water height sensor design files/V0.5.1/CAD/CAD V 0.5.2/Battery 2.ipt
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

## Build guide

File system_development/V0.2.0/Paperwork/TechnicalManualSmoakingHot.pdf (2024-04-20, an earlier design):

## Technical Manual for Data transfer system for UAV-deployed sensor packages

## Smoaking Hot

4/19/2024

## Data transfer system for UAV-deployed sensor packages

## Team:

## Smoaking Hot

## Members:

## Jared Peters, Steve Howard, and Jacob Tapp (Team Lead)

## Date:

## April 19th, 2024

## Statement:

## This is submitted in partial fulfillment of the requirements for ELCT 404 Spring 2024 at the University of South Carolina. It shall be understood that submission of this document by one member of the team means that each other member of the team

has individually approved of its content.

## Table of Contents

Introduction:

The project consists of two devices, the sensor package and the waystation. The sensor package is a standalone device that runs on a battery and is small enough to be drone deployed. It gathers accelerometer data, stores it into a SD card in csv format, and transmits the data to the waystation. These functions are performed by the C++ code executed on the Teensy 4.0 microcontroller board that uses libraries specifically made for the modules chosen. The Teensy interfaces with the SD card and the nRF24L01 via SPI bus. Refer to operating instructions for information on operating the sensor package. The sensor package can store 8 Gb of data with the 8 Gb SD card used on it currently and can collect at a sampling rate as high as 1 kHz.

The waystation is a device that can be put into a box and mounted on a pole. It receives the accelerometer data from the sensor package and performs computations on the data. These computations consist of FFT, mean, and standard deviation. The Raspberry Pi receives data via serial connection through a Teensy 4.0 connected to an nRF24L01. The data now on the Raspberry Pi is processed using a python program to output the required calculations. Refer to operating instructions for information on operating the waystation. The waystation receives data at a rate of 456.4 points per second and the time to compute the FFT is 0.00167 seconds per value.

Operating Instructions:

Materials Needed:

- Raspberry Pi Model 4B
- HDMI Cable
- HDMI to USB-C Adapter
- 3 MicroUSB cable
- Power Block
- Keyboard
- Mouse
- Wall Plugin
- 2 Teensy 4.0
- MPU 6050
- 2 nRF24L01
- SD card module
- 32 Gb SD card
- SD card of any value greater than 4Gb

Waystation:

To begin operating this device you would need to connect the Raspberry Pi Model 4B to an HDMI cable that connects to a screen that supports HDMI using a HDMI to USB-C adapter as shown below.

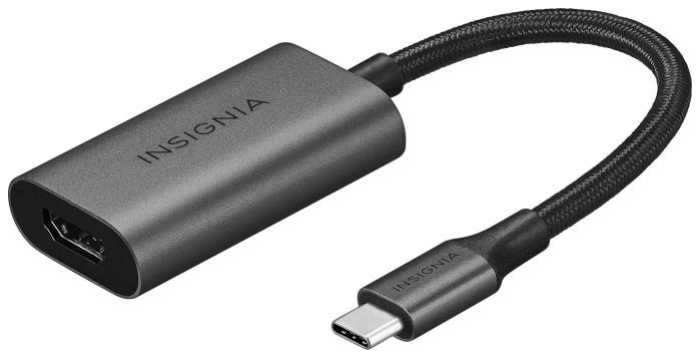
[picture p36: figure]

Figure 1: HDMI to USB-C adapter

Next you would connect a keyboard and mouse to the Raspberry Pi Model 4B as shown. Then you connect the Teensy 4.0 to the Raspberry Pi Model 4B via USB as shown. Once all these are connected, you can power the Raspberry Pi Model 4B using a power block and a micro-USB.

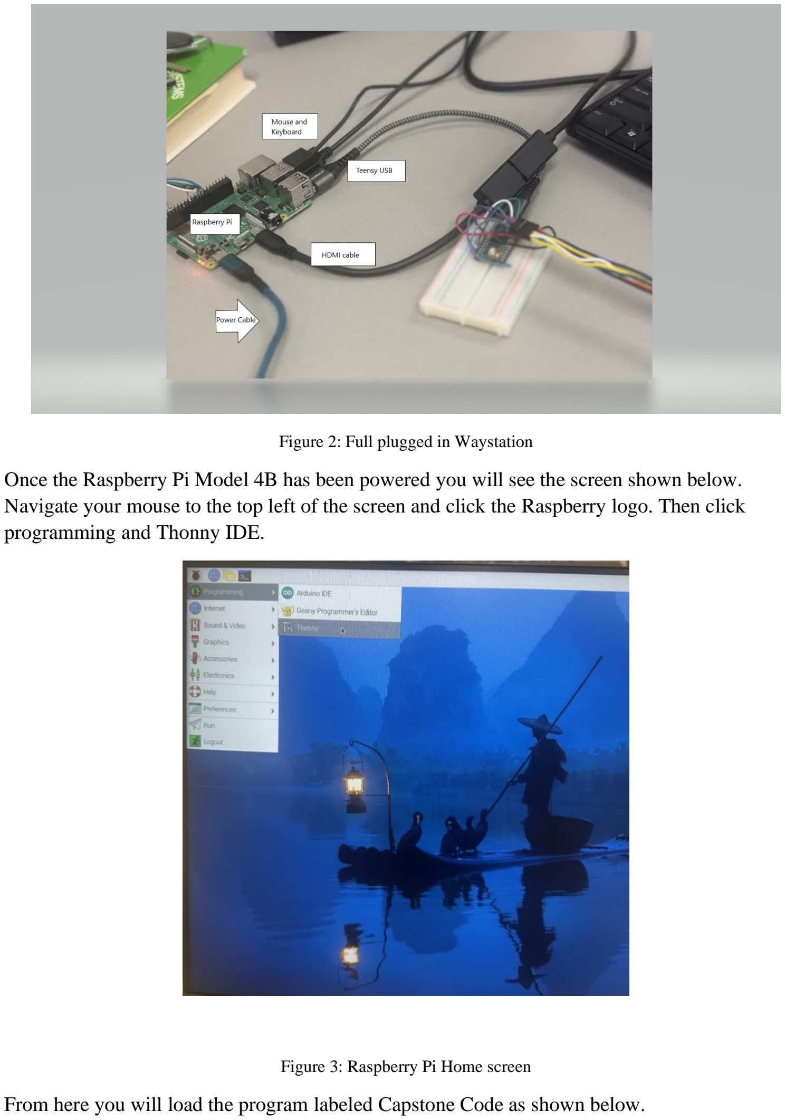
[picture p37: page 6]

Figure 2: Full plugged in Waystation

Once the Raspberry Pi Model 4B has been powered you will see the screen shown below. Navigate your mouse to the top left of the screen and click the Raspberry logo. Then click programming and Thonny IDE.

Figure 3: Raspberry Pi Home screen

From here you will load the program labeled Capstone Code as shown below.

It should be in the following directory: smoakinghot/Documents/Capstone Code

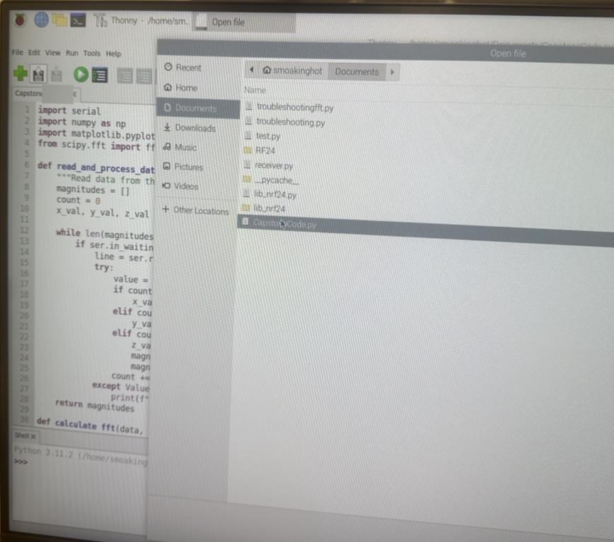
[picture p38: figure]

Figure 4: Program Labeled Capstone Code

From here simply click Run and it will wait for sensor package data.

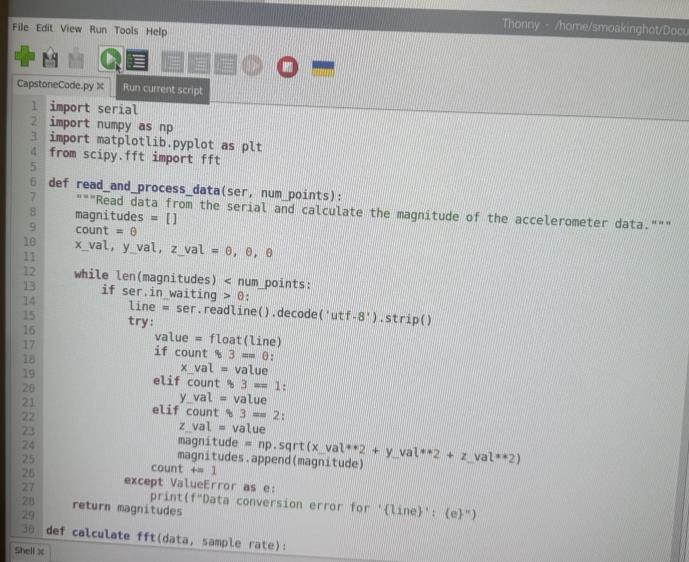
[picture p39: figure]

Figure 5: Run Button
Sensor Package:

The sensor packages are ready for deployment so all you would need to do is connect it to a power source using micro-USB as shown below and it will begin collecting and sending data. To restart the sensor package with its current working iteration, you have to unplug the micro usb and plug it back in. Do not press the button on the Teensy to restart the board. This has caused issues with the sensor package causing it to not function properly. If this does happen, then you must reupload the code onto it.

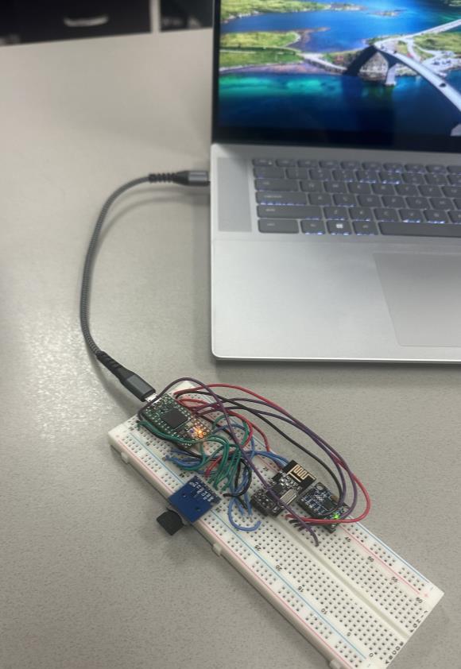
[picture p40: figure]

Figure 6: Sensor Packaged Powered

## Technical Description

Team Philosophy:

Our team's vision is to provide smoking hot products that are innovative and reliable. This is achieved by our philosophy that centers around ease and scalability. To accomplish this we use affordable and reusable materials in our products that can be easily repeated and flexible to change and troubleshooting. To increase our products' lifetime, we implement risk mitigation tactics to prepare for hazardous conditions where our waystation and sensor packages will be located.

Components and Circuits:

The sensor package contains an SD card module, nRF24L01, MPU6050, and a Teensy 4.0 while the waystation contains a Raspberry Pi 4B, Teensy 4.0, and an nRF24L01.

The SD card module interfaces with an SD card to write and read data from it. It is connected to a controller or other device via Serial Peripheral Input bus or SPI bus for short. For our usage, the Module is wired to the Teensy 4.0 microcontroller.

The nRF24L01 which is used on both the sensor package and the waystation is a wireless module that uses radio to communicate. Like the SD card, it also connects via SPI bus to the Teensy 4.0 on both the sensor package and the waystation. There are two configurations of the board. One configuration, the nRF24L01, is smaller with limited range and contains an internal antenna. The second configuration, the nRF24L01+, is a larger board with longer range capability and comes with an external antenna. The plus version of the board requires a more stable supply of power to operate.

The MPU6050 is a multipurpose sensor that collects accelerometer data, gyroscope data, and internal temperature. The accelerometer data, the focus of our project, is gathered in gravity magnitudes. The device connects to the analog pins of the Teensy 4.0.

The Teensy 4.0 is a programmable microcontroller prototyping board that uses Arduino IDE in C++. The device has analog pins, one SPI bus, and digital pins. For our purposes it functions as the brain of the sensor package and the receiver go-between for the waystation.

The Raspberry Pi 4 B is a general-purpose computer aimed at providing anyone with internet access to a reasonably powerful computing device. It is powerful enough to function as the waystation for our purposes. Its high processing power makes it an excellent option for generating FFTs.

In figure 7 below is a circuit schematic for the sensor package that illustrates its connections to each of its components. The schematic was made in KiCAD.

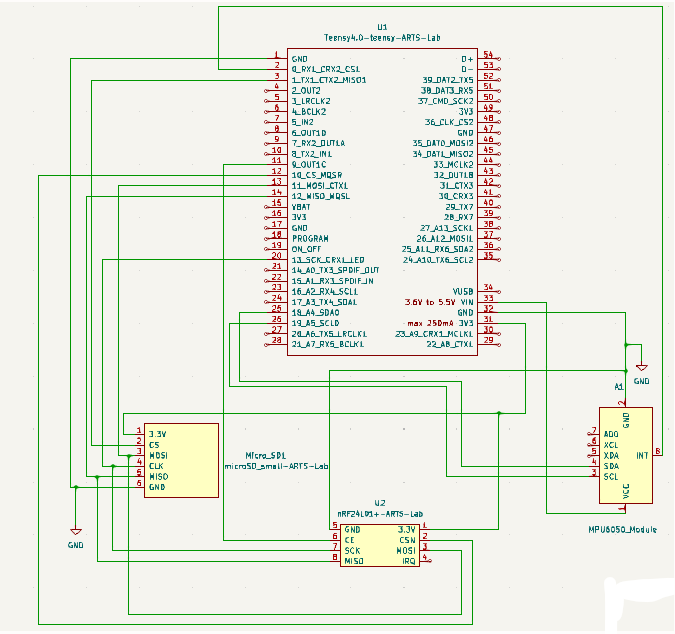
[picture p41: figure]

Figure 7. Sensor package circuit schematic.

System Performance:

The Sensor package is a device with several different components each boasting their own specifications that affect the overall performance of the system. It is important to note the limitations of these components as well as the limitations of the software.

As noted in the introduction, The MPU6050 has a limit of 1kHz sampling rate which is noted in its datasheet. The device has no lower limit and can be adjusted for in the code accordingly.

The nRF24L01 is reportedly capable of about 100 meters with the nRF24L01+ being capable of up to 1000 meters. We did not achieve this range in our project; however, we believe that is due to issues providing the device with a strong steady signal. In our tests, we achieved 8 feet between the transmitter and receiver. It is worth noting that this range was tested using the nRF24L01, not the plus as it would not work at all due to power supply issues.

The SD card performs well with a standard read/write speed of 12.5 MB/s and a high speed twice that value. Unless you wanted to store millions of data points, the read/write speed would never affect the system in any noticeable way. It is worth noting that the standard number of points we need to collect is 70,000.

The software of the sensor package and the waystation are the most impactful in the system's performance. For the sensor package to gather data, it needs to do so at the users specified rate, meaning that data collection time is very variable. It is worth noting that data transfer cannot begin before data collection is complete, because the time required to transmit the data points in the middle of data collection would change the sampling rate in unpredictable ways. The variability in data collection time due to user requests can mean that data collection could take 1 second with a higher sampling rate and a lower number of samples or it could take an infinite amount of time. For testing purposes, we used 1000 data points and a sample time of 9.5 seconds.

The performance of the software on the waystation is also directly dependent on the number of data points collected by the sensor package. The Raspberry Pi can generate an FFT at a rate of 456.4 points per second. Thus, there is a direct correlation between the number of data points and the time it takes to generate the FFT. This means that with 70,000 data points it will take 153 seconds (about 2 and a half minutes) to generate the FFT for that number of points.

Performance Trade-offs:
One of the main trade-offs in the design of this device is the trade-off between precision and time. This is referring to the correlation between data points and processing time being directly proportional.

Another trade-off was in the problems we devoted our attention to. As stated above, we only achieved an effective wireless communication range of 8 feet, while other users using the same module reported a greater range of about 100 meters (about 328.08 ft). Rather than trying to solve this issue, after bringing it up with our sponsor, we decided to devote our attention to optimizing our software. At the time, neither we nor our sponsor were aware of the nRF24L01 module Power demands and the Teensy 4.0’s limited ability to supply that power.

Reprogram the system:

It is important to note that the number of data points collected and the sampling rate are designated in the code of the sensor package. To change these values, edit the code slightly. To change the number of samples, change the value for the datapoints variable defined early on in the code before the setup. To change the sample rate, change the wait time in the data collection loop. This will determine the wait time between the collection of each point.

It is also possible to change the name of the file the data is stored in. This can be changed by editing the line that starts with “SD.Open”.

Standards/Codes Adhered To:

For the purposes of our project, there were no standards we had to adhere to. This is due to the nature of our sponsors' work, being research and not shipping products to be used practically. We were told that the waystation and sensor package were for proving functionality purposes only.

Block Diagrams:

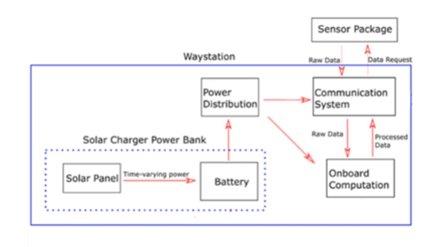
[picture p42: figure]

Figure 8. System block diagram for the waystation

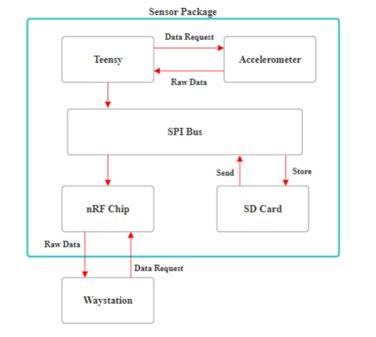
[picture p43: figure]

Figure 9. System block diagram for the sensor package

Troubleshooting Tips:

Hardware:

- Use a multimeter to test for continuity (buzz test) on the PCB’s or Breadboards
- Consult the wiring diagrams for the Sensor Package
- Review Data Sheets for specific expectations of a specific module

Software:

- Review the nRF libraries for extra troubleshooting code
- PrintRadioDetails() is a great tool to see if the radio is connected and initializing
- Don't be afraid to make it print something to the console to see if data is being sent to the right variable or radio
- Restart Application or Hardware
- Use the Reprogram button on Teensy 4.0
- Always save an extra file before editing the last so you know what you changed

## Appendix

Patent Search:

A patent search was conducted for our product at United States Patent and Trademark Office (USPTO) Online Directory. The following words were used in the advanced search category.

- Bridge Sensors
- Waystation
- Sensor Packages
- Bridge Data Collection

When reviewing the first ten patents of each search (40 total) none of the patents directly mentioned anything regarding our project or design. Although, we do not necessarily believe that this product passes the criteria for patentability due to its lack of novelty and the fact that it's open source for anyone to use.

Public Impact Statement:

In our ongoing commitment to public safety and traffic infrastructure, our latest innovation in bridge stability testing technology represents a significant advancement in the monitoring and maintenance of bridge structures. This technology employs a combination of advanced sensors and data analytics to assess the structural integrity of bridges in real-time, providing essential information that can prevent accidents and extend the lifespan of vital transportation assets.

Overall, we believe that this product will allow for safer communities, cost savings, and environmental protection from large structure collapses.

Prototype to Production Plan:

The next steps for our project to reach the overall goals of our design would be the following:

1. Turn the Waystation into a Transceiver
2. Remove the Interconnect Teensy in the Waystation
3. Order the new set of PCB’s
4. Design the Physical Waystation Cover
5. Increase Range of Sensor Packages

1: Turning the Waystation into a Transceiver

Instead of constantly waiting for the data to be sent to the waystation, ideally it would be user prompted. This would save on power expenses and the overall lifetime of our product.

2: Remove the Interconnect Teensy in Waystation

Currently wireless communications are done through nRF chips that are connected to the teensy in the way station that then uses a serial (micro-USB) connection to the Raspberry Pi to conduct the onboard processing. Ideally this is not efficient because it makes the product cost more and has more troubleshooting possibilities. This can be removed by connecting the GPIO pins directly to the nRF module and changing the program to enable communication to other teensys.

3: Order New PCB’s

Our product currently is using a breadboard due to the first set of PCBs not having a power regulating addition to power the nRF24L+ (external antenna) due to it needing more consistent power than the original nRF module. The design is already made and waiting to be ordered.

4: Design Physical Waystation Cover

All the testing done has been done inside due to the lack of range but for practical use our product will need an environmentally-proof cover that is secure for public use.

5: Increase Range of Sensor Packages

When designing this product, we were using the nRF24L01 but ended up purchasing nRF24L01+ for longer ranges. This needs to be implemented and tested.

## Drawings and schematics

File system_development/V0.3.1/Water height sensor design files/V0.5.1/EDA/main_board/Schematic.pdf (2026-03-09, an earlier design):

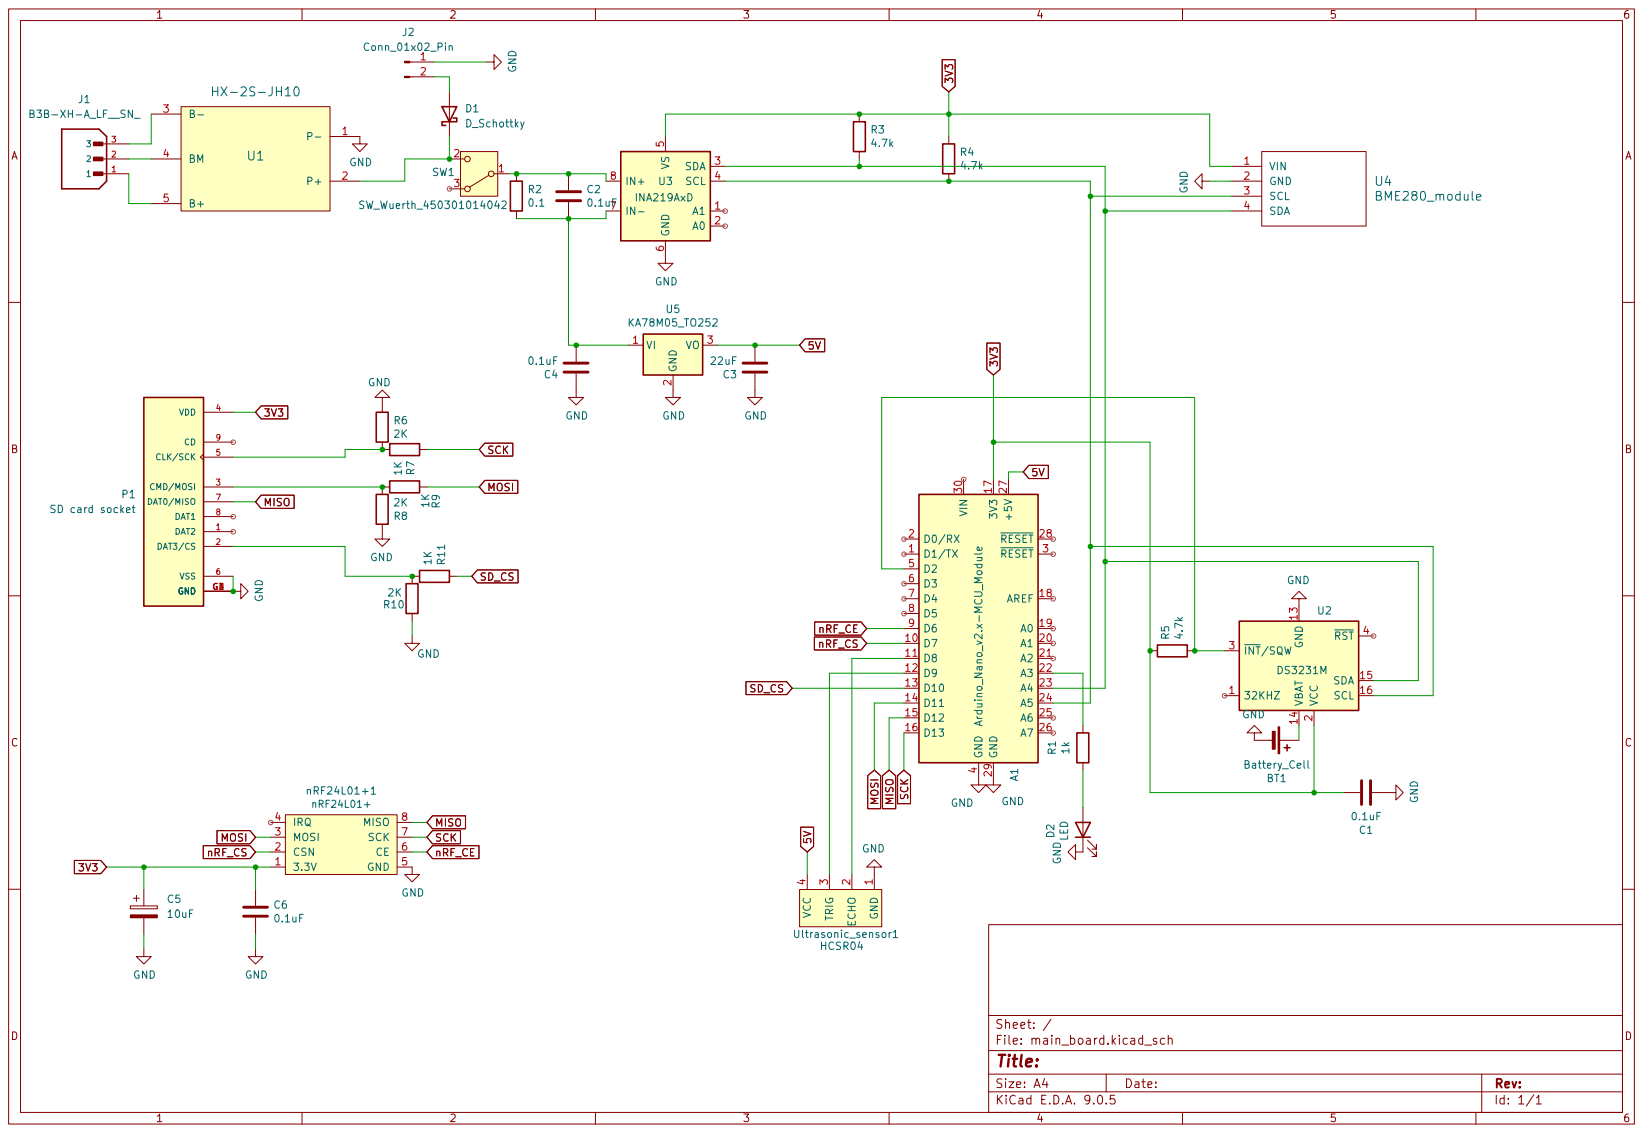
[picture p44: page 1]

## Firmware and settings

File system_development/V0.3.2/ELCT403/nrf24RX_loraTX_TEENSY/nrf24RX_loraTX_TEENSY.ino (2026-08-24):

/*
The code was developed to complete course assigments and an in-lab demo for ELCT403 Senior Design I.

This code demonstrates:
  1. reception of data from a mock field sensor via nRF24 radio module
  2. storage of that data to internal array in format comparable to sample data in water.h
  3. transmission of sample data contained in water.h via RFM96W LoRa radio module
  4. adjustment of LoRa radio bandwidth setting to observe packet-time-on-air (TOA)
of a Teensy 3.5 MCU servicing the PHY aspects of a field station (rx/tx radio packets).

By field station it is meant residing in the vicinity of nRF24 compatible, deployed field sensors, which
having collected data wirelessly from these sensors, sends edge-processed data values to a base station
of an equivalent architecture via LoRa radio interface.

It is acknowledged that data in array "log_buffer" should be relayed to RPi in final project iterations,
through development of state logic to interface with a supervisory single board computer.
*/

#include <RadioLib.h>
#include <SPI.h>
#include "water.h"

#define MAX_HEIGHT_VAL 14   // water.h sample data contains 14 columns

#define RFM96W_CS 10
#define RFM96W_IRQ 24
#define RFM96W_RST 25
#define RFM96W_FREQ 433.6
#define RFM96W_BANDWIDTH 125
#define RFM96W_SF 6
#define RFM96W_CODING_RATE 5
#define RFM96W_SYNC_WORD 0x34  // default for LoRaWAN
#define RFM96W_OUTPUT_POWER 2  // dBm
#define RFM96W_PREAMBLE_LEN 60  // expressed in symbols
#define RFM96W_GAIN 0  // of the receiver
#define RFM96W_CONFIG \
  RFM96W_FREQ, RFM96W_BANDWIDTH, RFM96W_SF, RFM96W_CODING_RATE, \
  RFM96W_SYNC_WORD, RFM96W_OUTPUT_POWER, RFM96W_PREAMBLE_LEN, RFM96W_GAIN

#define NRF24_PAYLOAD_LEN 8
#define NRF24_PK_LEN 11
#define NUM_SENSOR 2
#define LOG_BUF_LEN 1
#define LORA_PAYLOAD_LEN 8
#define LORA_PK_LEN 19

struct LoRa_PK_t;
struct nRF24_PK_t;
void decode_nRF24(nRF24_PK_t * raw_pks, double * _log_buffer, int RAW_PK_LEN = NRF24_PAYLOAD_LEN, int LOG_ROW_NUM = LOG_BUF_LEN, int LOG_COL_NUM = MAX_HEIGHT_VAL);
void cast_double_uint8_t_payload(double * in, LoRa_PK_t * pyld_in, int pyld_len, uint8_t opt);

/******************************************************************************
 * nRF24 payload structure
 */
struct nRF24_PK_t{
  uint8_t sens_id;      // supports unique field stations ids
  uint8_t type;         // number according to column number in header table
  uint8_t base10_exp;   // allow noninteger payload values
  uint8_t payload[NRF24_PAYLOAD_LEN];   // 8 bytes
};

/******************************************************************************
 * LoRa payload structure
 */
struct LoRa_PK_t{
  uint8_t fstn_id;    // supports unique base station ids
  uint8_t type;       // supports generic type, such as mean water level
  uint8_t base10_exp;   // allow noninteger payload values
  uint8_t timestamp[LORA_PAYLOAD_LEN];    // 8 bytes
  uint8_t payload[LORA_PAYLOAD_LEN];      // 8 bytes
};

LoRa_PK_t LoRa_PK;
nRF24_PK_t nRF24_PK;

RFM96 lr_radio = new Module(RFM96W_CS, RFM96W_IRQ, RFM96W_RST);

nRF24 rf24_rad = new Module(9, 17, 16);

// flag to indicate that a packet was received
volatile bool nRF24_rx_flg = false;
void setFlag_nrfRX(void) { nRF24_rx_flg = true; }

volatile bool LoRa_tx_flg = true;
void setFlag_loraTX(void) { LoRa_tx_flg = true; }

int nRF24_rx_ret; int nRF24_sz;

int LoRa_tx_ret;

// memory location to receive raw nRF24 packets
nRF24_PK_t nRF24_buffer[MAX_HEIGHT_VAL] = {};

// memory location to populate in height data byte stream; first in, last out
double log_buffer[LOG_BUF_LEN][MAX_HEIGHT_VAL] = {};
double * log_buf_ptr = &(log_buffer[0][0]);

/******************************************************************************
 * nRF24 packet structure to height data header (>32 byte)
 */
void decode_nRF24(nRF24_PK_t * raw_pks, double * _log_buffer_ptr, 
                  int RAW_PK_LEN = NRF24_PAYLOAD_LEN,
                  int LOG_ROW_NUM = LOG_BUF_LEN, 
                  int LOG_COL_NUM = MAX_HEIGHT_VAL) {

  uint64_t uint64_payload = 0;
  double d_payload = 0;
  int n = 0;
  int dec_num = 0;

  for (int i = 0; i < LOG_COL_NUM; ++i) {
    for (int j = 0; j < RAW_PK_LEN; ++j) {
      uint64_payload = (uint64_payload << 8) | (uint64_t) raw_pks[i].payload[j];
    }

    n = static_cast<double>(raw_pks[i].type);
    dec_num = static_cast<double>(raw_pks[i].base10_exp);

    d_payload = (double) (uint64_payload / pow(10.0, dec_num));
  
    *(_log_buffer_ptr + n) = d_payload;

  }
}

/******************************************************************************
 * input double value, separate into 8 bytes, pack into LoRa_PK_t instance
 */
void cast_double_uint8_t_payload(double * in, LoRa_PK_t * pyld_in, int pyld_len, uint8_t exp) {
  uint64_t temp_in; double temp_ind;
  temp_ind = (double) ((*in) * pow(10.0, (double)(exp)));
  temp_in =  (uint64_t) temp_ind;
  if (exp == 0) {
    for (int j = 0; j < pyld_len; ++j) {
      pyld_in->timestamp[pyld_len-j-1] = (uint8_t)( (temp_in >> 8*j) & 0xFFFFFFFFFFFFFFFF); // big endian
    } 
  } else {
  for (int j = 0; j < pyld_len; ++j) {
    pyld_in->payload[pyld_len-j-1] = (uint8_t)( (temp_in >> 8*j) & 0xFFFFFFFFFFFFFFFF); // big endian
  }
  }
}

float bw_param[10] = {7.8, 10.4, 15.6, 20.8, 31.25, 41.7, 62.5, 125, 250, 500};
int pwr_param[16] = {2, 3, 4, 5, 6, 7, 8, 9, 10, 11, 12, 13, 14, 15, 16, 17};

void setup() {
	
  Serial.begin(115200);
/* Setup nRF2401L+ module
 */
  Serial.print(("[nRF24] Initializing ... \r\n"));
  nRF24_rx_ret = rf24_rad.begin();
  if(nRF24_rx_ret == RADIOLIB_ERR_NONE) {
    Serial.print(("success!\r\n"));
  } else {
    Serial.print(("failed, code \r\n"));
    Serial.print(nRF24_rx_ret);
    while (true) { delay(10); }
  }

  Serial.print("[nRF24] Setting address for receive pipe 0 ... \r\n");
  byte addr[] = {0x01, 0x23, 0x45, 0x67, 0x89};
  nRF24_rx_ret = rf24_rad.setReceivePipe(0, addr);
  if(nRF24_rx_ret == RADIOLIB_ERR_NONE) {
    Serial.print(("success!\r\n"));
  } else {
    Serial.print(("failed, code \r\n"));
    Serial.print(nRF24_rx_ret);
    while (true) { delay(10); }
  }

  rf24_rad.setPacketReceivedAction(setFlag_nrfRX);

  // start listening
  Serial.print(("[nRF24] Starting to listen ... \r\n"));
  nRF24_rx_ret = rf24_rad.startReceive();
  if (nRF24_rx_ret == RADIOLIB_ERR_NONE) {
    Serial.print(("success!\r\n"));
  } else {
    Serial.print(("failed, code \r\n"));
    Serial.print(nRF24_rx_ret);
    while (true) { delay(10); }
  }

/******************************************************************************
 * Initizalize LoRa packet type structure
 */
  LoRa_PK.fstn_id = 11;
  LoRa_PK.base10_exp = 4;
  LoRa_PK.type = 34;
  cast_double_uint8_t_payload(&(height_data[0][0]), &(LoRa_PK), LORA_PAYLOAD_LEN, 0*LoRa_PK.base10_exp);
  
  cast_double_uint8_t_payload(&(height_data[0][1]), &(LoRa_PK), LORA_PAYLOAD_LEN, LoRa_PK.base10_exp);

 /*****************************************************************************
 * Setup LoRa module
 */	
  Serial.printf("[SX1276] initializing ...");
  // initialize SX1276 with user settings:
  //LoRa_tx_ret = lr_radio.begin(434.0, 125.0, 9, 7, RADIOLIB_SX127X_SYNC_WORD, 2, 8, 0);
  LoRa_tx_ret = lr_radio.begin(434.0, bw_param[0], 9, 7, RADIOLIB_SX127X_SYNC_WORD, 2, 8, 0);
  lr_radio.setOutputPower(pwr_param[0]);

  if (LoRa_tx_ret == RADIOLIB_ERR_NONE) { Serial.printf("success!"); } else {
    Serial.printf("failed, code ");
    Serial.println(LoRa_tx_ret);
    while (true) { delay(10); }
  }

  if (LoRa_tx_ret == RADIOLIB_ERR_NONE) { Serial.printf("[SX1276] standby\r\n"); }

  lr_radio.setPacketSentAction(setFlag_loraTX);
  //Serial.print("[SX1276] Sending first packet ... \r\n");
  //stat = lr_radio.startTransmit(LoRa_PK, sizeof(LoRa_PK)); 
}

int k_nRF24 = 0;
uint8_t nRF24_read_buf[NRF24_PK_LEN] = {};
nRF24_PK_t * nRF24_buf_ptr = &(nRF24_buffer[k_nRF24]);
int k_LoRa = 0;

uint8_t LoRa_write_buf[LORA_PK_LEN] = {};
uint8_t * LoRa_write_buf_ptr = &(LoRa_write_buf[0]);

int i_bw = 0;
int i_pwr = 0;

void loop() {
    if(nRF24_rx_flg) {

      nRF24_rx_flg = false;
      rf24_rad.finishReceive();
      nRF24_sz = rf24_rad.getPacketLength();
      nRF24_rx_ret = rf24_rad.readData( nRF24_read_buf, NRF24_PK_LEN);

      Serial.printf("\nnRF24_sz:\t%d\r\n", nRF24_sz);
      // transfer to 2D array with MAX_HEIGHT_VAL number of rows
      memcpy(&(nRF24_buffer[k_nRF24]), nRF24_read_buf, NRF24_PK_LEN);

      if (nRF24_rx_ret == RADIOLIB_ERR_NONE) {
      // packet was successfully received
      // print raw data of the packet
        Serial.printf("[nRF24] sens_id:\t%d\r\n", nRF24_buffer[k_nRF24].sens_id);
        Serial.printf("[nRF24] type:\t%d\r\n", nRF24_buffer[k_nRF24].type);
        Serial.printf("[nRF24] base10_exp:\t%d\r\n", nRF24_buffer[k_nRF24].base10_exp);
        //Serial.printf("[nRF24] payload:\t%d\r\n", nRF24_buffer[k_nRF24].payload);
        Serial.printf("[nRF24] payload:\t%u %u %u %u %u %u %u %u\t\r\n", nRF24_buffer[k_nRF24].payload[0], nRF24_buffer[k_nRF24].payload[1], nRF24_buffer[k_nRF24].payload[2], nRF24_buffer[k_nRF24].payload[3], nRF24_buffer[k_nRF24].payload[4], nRF24_buffer[k_nRF24].payload[5], nRF24_buffer[k_nRF24].payload[6], nRF24_buffer[k_nRF24].payload[7]);
        Serial.printf("RX events:\t%d\r\n\n", k_nRF24);
      } else {
      // some other error occurred
        Serial.print(("[nRF24] Failed, code \r\n"));
        Serial.print(nRF24_rx_ret);
      }

      if (k_nRF24 == (MAX_HEIGHT_VAL-1)) {
        Serial.print("[nRF24] nRF24_buffer full:\r\n");
        Serial.print("[nRF24] decoding received packets:\r\n");
        k_nRF24 = 0;
        decode_nRF24(nRF24_buffer, log_buf_ptr);

        for (int i = 0; i < MAX_HEIGHT_VAL; ++i) {
          Serial.printf("[node] %s:\t%f\r\n", height_header[i], log_buffer[0][i]);
        }
      } else {
        ++k_nRF24;
      }
      nRF24_buf_ptr = &(nRF24_buffer[k_nRF24]);
      rf24_rad.startReceive();
    }

  if(LoRa_tx_flg) {
    LoRa_tx_flg = false;

	  if (LoRa_tx_ret == RADIOLIB_ERR_NONE) { Serial.print("Packet sent successfully\r\n"); }
	  else {
      Serial.print(("[SX1276] Failed, code \r\n"));
      Serial.print(LoRa_tx_ret);
	  }
	
	  lr_radio.finishTransmit();

    delay(4000);

    cast_double_uint8_t_payload(&(height_data[0][k_LoRa]), &(LoRa_PK), LORA_PAYLOAD_LEN, LoRa_PK.base10_exp);

    memcpy(LoRa_write_buf_ptr, &(LoRa_PK), sizeof(LoRa_PK));

    LoRa_tx_ret = lr_radio.startTransmit(LoRa_write_buf_ptr, sizeof(LoRa_PK));

    Serial.print("[SX1276] Transmitting packet:\r\n");
    Serial.printf("\tfstn_id:\t%d\r\n", LoRa_PK.fstn_id);
    Serial.printf("\tcontent_type:\t%d\r\n", LoRa_PK.type);
    Serial.printf("\tbase10_exp:\t%d\r\n", LoRa_PK.base10_exp);
    Serial.printf("\traw timestamp:\t%u %u %u %u %u %u %u %u\t\r\n", LoRa_PK.timestamp[0], LoRa_PK.timestamp[1], LoRa_PK.timestamp[2], LoRa_PK.timestamp[3], LoRa_PK.timestamp[4], LoRa_PK.timestamp[5], LoRa_PK.timestamp[6], LoRa_PK.timestamp[7]);
    Serial.printf("\traw payload:\t%u %u %u %u %u %u %u %u\t\r\n", LoRa_PK.payload[0], LoRa_PK.payload[1], LoRa_PK.payload[2], LoRa_PK.payload[3], LoRa_PK.payload[4], LoRa_PK.payload[5], LoRa_PK.payload[6], LoRa_PK.payload[7]);
    Serial.printf("\tTX events:\t%d\r\n\n", k_LoRa);
    Serial.printf("\ttime on air:\t%d\r\n", lr_radio.getTimeOnAir(sizeof(LoRa_PK)));
    Serial.printf("\tpower:\t%d\r\n", pwr_param[i_pwr]);
    ++k_LoRa;
    if (k_LoRa == MAX_HEIGHT_VAL) { k_LoRa = 0; }

    if ( ((k_LoRa % 4) == 0) ) { ++i_bw; }

    if ( i_bw == 10) { i_bw = 0; }
  }

}

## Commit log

2023-12-01 PCB Design V0.4.0
    [CAPSTONE_sensor_unitV0_4.kicad_pcb, CAPSTONE_sensor_unitV0_4.kicad_sch, CAPSTONE_sensor_unitV_3.kicad_pcb]
2023-12-05 V0.4.1 added
    [CAPSTONE_sensor_unitV0_4_1.kicad_pcb, CAPSTONE_sensor_unitV0_4_1.kicad_sch]
2024-04-20 Added PCB V0.4.4, RPi code, and Technical Manual
    [CAPSTONE_sensor_unitV0_4.kicad_pcb, CAPSTONE_sensor_unitV0_4.kicad_sch, CAPSTONE_sensor_unitV0_4_1.kicad_pcb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]
2025-03-24 added v0.5.0
    [CAPSTONE_sensor_unitV0_4_4.kicad_pcb, CAPSTONE_sensor_unitV0_4_4.kicad_sch]
2025-10-23 added v0.3 for the wireless access hub.
    [CAPSTONE_sensor_unitV0_4.kicad_pcb, CAPSTONE_sensor_unitV0_4.kicad_sch, CAPSTONE_sensor_unitV0_4_1.kicad_pcb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]
2025-11-03 BOM Update
2025-11-04 BOM Updates
    [Wireless Communication Bill of Materials.xlsx]
2025-11-05 BOM added
    [bill_of_materials.xlsx]
2025-11-05 and 0.0.x to version names
    [CAPSTONE_sensor_unitV0_4.kicad_pcb, CAPSTONE_sensor_unitV0_4.kicad_sch, CAPSTONE_sensor_unitV0_4_1.kicad_pcb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]
2025-11-11 BOM updated
    [bill_of_materials.xlsx]
2025-11-11 EDA files added, BOM modified, Readme updated
    [Base_station_PCB_V0.3.1-B_Cu.gbr, Base_station_PCB_V0.3.1-B_Mask.gbr, Base_station_PCB_V0.3.1-B_Paste.gbr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]
2025-11-11 Update README
    Added PCB view images to the README.
2025-11-11 gerbers added
2026-03-09 stage height pcb and data added
    [254.step, ANSI (in).dwg, ANSI (in).idw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]
2026-08-24 Add files via upload
    Adding initial Arduino sketches used in ELCT403 Spring 2026 semester
